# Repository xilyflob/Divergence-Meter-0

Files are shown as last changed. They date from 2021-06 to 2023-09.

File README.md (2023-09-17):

# Purpose
Recreate Tom Titor's original Divergence Meter project with more up to date hardware and software. Also taking into account current tools and services avalible to makers.

# Goals
* Maintain level of visual accuracy to the show that was in the original.
* Keep code size down so if people don't want to use updated hardware they can still fit it on the old chip.
  * Currently failing this, assembly output from the C code has proven much less efficient than I had anticipated.
* Provide more accessible code for the microcontroller so makers can make changes on their own easier than with the assembly version, also commented well enough that it is easy to understand.
* Produce at least proper drawings for the physical construction. Ideally a solid model as well, however there may be license issues with that.

# Software Used
* Autodesk Eagle
  * Originally used to do the PCB design, the SMT versions were later converted to KiCad. Earlier, simpler converts and redesigns currently remain in those file types.
* KiCad
* MPLAB X IDE
  * XC8 compiler
* Solidworks

# Build Log
Available on [Imgur](https://imgur.com/a/QL4b4lS), maybe one day I will make a website for better layout and such.

# Current Status 9/16/23
Long time no update :)

Lost lots of motivation to work on this after I realized that there are more I2C issues. Regular writes flat out dont work, you make it though the code but they don't take on the RTC. Currently implementing a fix that is reccomended in the 8803 manual, hopefully it works.

No changes to hardware this time, I do have a bunch of ideas for a Rev B including actually hooking up the INT line from the RTC which could prove EXTREMELY useful in making the software less "busy".

Motivation remains hard, hope to keep at this as well as I can.

# Background
Full disclosure time, I have zero formal training in coding or electrical engineering, I am actually a machinist (I guess that makes me qualified to fab the actual box though). On top of this, this is my first time doing any assembly reading, C coding, coding for microchips, or circuit board design. If I make a mistake that you see, PLEASE tell me.

I've wanted to do Tom's divergence meter project basically since I first found it after watching the Steins;Gate show. Never actually had the drive to do it though. Don't ask me why, but at some point in 2021 I went to look at the site, only to find it gone. Wayback Machine has an archive, but more importantly whoever the saint is that runs brotoro.com made a complete functional rehost of the site, which is much less clunky than Wayback. Would definitely say that almost losing that info really pushed me to start working on this.

# Thanks
* Jonathan from [SWISSNIXIE](http://www.swissnixie.com/) for helping me understand nixie tube amperage and resistance requirement as well as lending prototyping advice on the HV5623 drivers.
* John from [Taylor Electronics](https://www.shop-tes.com/) for providing data on the current usage of the 1364 HVPS in this specific application.
* /r/PrintedCircuitBoard for doing their best to answer my questions

# Licence
Hardware: Creative Commons Attribution-ShareAlike 4.0 International

Software: GNU GPL V3.0

Also just let me know if you use anything. Or if you make this! Would love to see people's projects.

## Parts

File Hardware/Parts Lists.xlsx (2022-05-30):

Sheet: Tom Titor Parts List
Quantity | Part | Description | Mouser Part # | Source/Price | Notes
1 |  | Main Printed Circuit Board
1 |  | Tube Printed Circuit Board
1 | U3 | PIC16F628A processor | 579-PIC16F628A-E/P or 579-PIC16F628A-I/P | mouser.com $2.23
1 | U1 | LM7805 1A 5V regulator TO-220 | 512-LM7805CT | mouser.com $0.62
1 | D1 | 1N4007 | 512-1N4007 | mouser.com $0.09
1 | F1 | Fuse 0.8A 5mm x 20mm | 504-BK/S500-800-R | mouser.com $0.21
2 | F1 | Fuse Holder Clips | 534-3519 | mouser.com $0.13 each
1 | J2 | DC Power Jack 2.5mm | 806-KLDX-0202-B | mouser.com $0.66
1 | X2 | Crystal 32.768 KHz 12.5 pF 20ppm* | 559-NC38-LF | mouser.com $0.63 | Not needed if using the DS3232 clock
1 | U4 | DS1307+ Real Time Clock* | 700-DS1307 | mouser.com $4.03 | Not needed if using the DS3232 clock
1 | U2 | 1364 High Voltage Power Supply | 1364 HVPS-H | tayloredge.com $13.95
1 | C2 | 330uF Electrolytic Capacitor |  | (comes with 1364 HVPS-H)
3 | U6, U7, U8 | Supertex Serial to Parallel Converter | 689-HV5622PG-G | mouser.com $7.51 each | 220V 32Ch Open Drain Outputs
8 | T0-7 | IN-14 Nixie Tubes |  | eBay | I recommend getting tubes that are "New Old Stock" and "guaranteed tested" (or test them yourself before you install them)
1 | C1 | 33uF Electrolytic Capacitor | 140-RGA330M1EBK0511G | mouser.com $0.08
5 | C3, C4*, C8, C9, C10 | 0.1uF Capacitor MLCC | 810-FK18X7R1H104K | mouser.com $0.21 | C4 not needed if using the DS3232 clock
5 | R1, R2, R3, R4, R32 | 10K Resistor | 660-CF1/4C103J | mouser.com $0.15 each
1 | R31 | 470K Resistor | 660-CF1/4C474J | mouser.com $0.15
8 | R7, R8, R9, R10, R11, R12, R13, R14 | 33K Resistors | 271-33K-RC | mouser.com $0.09 each
16 | R15, R16, R17, R18, R19, R20, R21, R22, R23, R24, R25, R26, R27, R28, R29, R30 | 243K Resistor | 271-243K-RC | mouser.com $0.09 each
1 | R5 | Trimmer Resistor 100K Sealed 6mm Square 12-turn | 81-PV37W104C01B00 | mouser.com $2.35
1 | J1 | 8 Pin header female | 575-010064 | mouser.com $8.85
1 | J3 | 6 Pin header female
3 | NC1-3 | 2 Pin header female
1 | J4 | 8 Pin header male | 575-093050 | mouser.com $8.39
3 | NC4-6 | 2 Pin header male
1 | U3 | 18-pin DIP Socket | 571-1-390261-5 | mouser.com $0.22
1 | B1 | Battery Holder for B1 | 534-103 | mouser.com $1.50
1 | B1 | CR2032 3V Lithium coin cell | 658-CR2032 | mouser.com $0.45
2 | SW1, SW2 | Micro miniature tactile switch | 655-FSMRA4JH | mouser.com $0.25 each
1 | SW3 | Slide Switch SPDT Right-Angle PC mount | 102-1261-EV | mouser.com $2.92 | not on mouser anymore, try 103-5007-EV
1 | B2 | 9V Battery Snap Connector | 270-324 | radioshack ($2.99 for pk. of 5)
1 | D2 | LED T-1 3mm (optional) | 78-TLHY4400 or 604-WP710A10YD | mouser.com $0.13 | only needed for debugging
1 | R6 | 270 Ohm (optional) | 660-CF1/4C271J | mouser.com $0.15
1 |  | Power Adapter 9V | PSSMV1USA | amazon.com $18.25 | Velleman Compact Universal DC Adapter Power Supply. The tip that matches power jack J2 has a 2.5mm inside contact diameter, and a 5.5mm outside diameter, with the +9 volts on the center contact and Ground on the barrel.
1 | U5 | Maxim DS3232SN# | 700-DS3232SN# | mouser.com $9.39 | alternative DS3232S#
1 | C7 | 0805 0.1uF Capacitor | 810-CGJ4J2X7R1H104K | mouser.com $0.09
1 | D3 | 1N5817 Schottky Diode | 512-1N5817 | mouser.com $0.43 | optional safety diode for battery protection
1 | SJ1 | Solder bridge |  |  | optional direct battery connection
1 | X1 |  |  |  | Not used
2 | C5,C6 |  |  |  | Not used
1 |  | Small machine screw |  |  | mounting U1
1 |  | PQFP-44 package |  |  | silk screen for U6-8

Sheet: Component Update Parts List
Quantity | Part | Description | Mouser Part # | Source/Price | Notes | General rule: always check buying in 10+ qty for better prices
1 |  | Main Printed Circuit Board |  |  |  | Updated component
1 |  | Tube Printed Circuit Board
1 | U3 | PIC16F628A processor | 579-PIC16F628A-E/P or 579-PIC16F628A-I/P | mouser.com $2.36
1 | U1 | MC7805 1A 5V regulator TO-220 | 863-MC7805CTG | mouser.com $0.62 | Original obsolete
1 | D1 | 1N4007 | 863-1N4007RLG | mouser.com $0.18 | Original obsolete
1 | F1 | Fuse 0.8A 5mm x 20mm | 504-BK1-S500-800-R | mouser.com $0.81 | Original fuse was $3, ridiculous
2 | F1 | Fuse Holder Clips | 534-3519 | mouser.com $0.21 each
1 | J2 | DC Power Jack 2.5mm | 806-KLDX-0202-B | mouser.com $0.54
1 | X2 | Crystal 32.768 KHz 12.5 pF 20ppm* | 559-NC38-LF | mouser.com $0.45 | Not needed if using the DS3232 clock
1 | U4 | DS1307+ Real Time Clock* | 700-DS1307 | mouser.com $3.97 | Not needed if using the DS3232 clock
1 | U2 | 1364 High Voltage Power Supply | 1364 HVPS-H | shop-tes.com $15.00
1 | C2 | 330uF Electrolytic Capacitor |  | (comes with 1364 HVPS-H)
3 | U6, U7, U8 | Supertex Serial to Parallel Converter | 689-HV5622PG-G | mouser.com $6.86 each
8 | T0-7 | IN-14 Nixie Tubes |  | eBay
1 | C1 | 33uF Electrolytic Capacitor | 647-UPW1E330MDD1TD | mouser.com $0.26 | Original now special order, other options also available
5 | C3, C4*, C8, C9, C10 | 0.1uF Capacitor MLCC | 810-FG18X7R1H104KNT0 | mouser.com $0.21 | Original not recommended for new designs. C4 not needed if using the DS3232 clock
5 | R1, R2, R3, R4, R32 | 10K Resistor | 660-CF1/4C103J | mouser.com $0.15 each
1 | R31 | 470K Resistor | 660-CF1/4C474J | mouser.com $0.15
8 | R7, R8, R9, R10, R11, R12, R13, R14 | 33K Resistors | 660-MF1/4DC3302F | mouser.com $0.055 each | Original only available in 1,000 qty., alternatives available.
16 | R15, R16, R17, R18, R19, R20, R21, R22, R23, R24, R25, R26, R27, R28, R29, R30 | 243K Resistor | 660-MF1/4DC2433F | mouser.com $0.055 each | Original only available in 200 qty.
1 | R5 | Trimmer Resistor 100K Sealed 6mm Square 12-turn | 81-PV37W104C01B00 | mouser.com $2.08
1 | J1 | 8 Pin header female | 575-010064 | mouser.com $8.39
1 | J3 | 6 Pin header female
3 | NC1-3 | 2 Pin header female
1 | J4 | 8 Pin header male | 575-093050 | mouser.com $7.14
3 | NC4-6 | 2 Pin header male
1 | U3 | 18-pin DIP Socket | 571-1-2199298-5 | mouser.com $0.30 | Original obsolete
1 | B1 | Battery Holder for B1 | 534-103 | mouser.com $1.51
1 | B1 | CR2032 3V Lithium coin cell | 658-CR2032 | mouser.com $0.33 | Drug store reccomended
2 | SW1, SW2 | Micro miniature tactile switch | 506-FSMRA4JH04 | mouser.com $0.25 each | Original obsolete
1 | SW3 | Slide Switch SPDT Right-Angle PC mount | 118-5MS1S102AM6QES | mouser.com $2.52 | Original mfr. seems to have rebranded
1 | B2 | 9V Battery Snap Connector | 534-232 | mouser.com $0.48 | Lmao RadioShack
1 | D2 | LED T-1 3mm (optional) | 78-TLHY4400 or 604-WP710A10YD | mouser.com $0.49 | Debug only
1 | R6 | 270 Ohm (optional) | 660-CF1/4C271J | mouser.com $0.15 | Debug only
1 |  | Power Adapter 9V | 418-TRE15090A12G13VI | mouser.com $13.70 | Original not for sale anymore. Requirements 9V output (800mA and 10W minimum per original), 2.5x5.5mm barrel, positive center, gnd outer
1 | U5 | Maxim DS3232SN# | 700-DS3232SN# | mouser.com $9.09 | Alternative clock. DS3232S# can be used as well.
1 | C7 | 0805 0.1uF Capacitor | 810-C2012X7R1H104KAE | mouser.com $0.24 | Original not recommended for new designs. Used if using the DS3232 clock option.
1 | D3 | 1N5817 Schottky Diode | 511-1N5817 | mouser.com $0.40 | Original obsolete. Optional safety diode for battery protection
1 | SJ1 | Solder bridge |  |  | Optional direct battery connection
1 | X1 |  |  |  | Not used
2 | C5,C6 |  |  |  | Not used
1 |  | Small machine screw |  |  | mounting U1
1 |  | PQFP-44 package |  |  | silk screen for U6-8

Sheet: Thru Hole Update Parts List
Quantity | Part | Description | Mouser Part # | Source/Price | Notes | General rule: always check buying in 10+ qty for better prices
1 |  | Main Printed Circuit Board
1 |  | Tube Printed Circuit Board
1 | U3 | PIC16F628A processor | 579-PIC16F628A-E/P or 579-PIC16F628A-I/P | mouser.com $2.36
1 | U1 | MC7805 1A 5V regulator TO-220 | 863-MC7805CTG | mouser.com $0.62
1 | D1 | 1N4007 | 863-1N4007RLG | mouser.com $0.18
1 | F1 | Fuse 0.8A 5mm x 20mm | 504-BK1-S500-800-R | mouser.com $0.81
2 | F1 | Fuse Holder Clips | 534-3519 | mouser.com $0.21 each
1 | J2 | DC Power Jack 2.5mm | 806-KLDX-0202-B | mouser.com $0.54
1 | U2 | 1364 High Voltage Power Supply | 1364 HVPS-H | shop-tes.com $15.00
1 | C2 | 330uF Electrolytic Capacitor |  | (comes with 1364 HVPS-H)
3 | U6, U7, U8 | Supertex Serial to Parallel Converter | 689-HV5622PG-G | mouser.com $6.86 each
8 | T0-7 | IN-14 Nixie Tubes |  | eBay
1 | C1 | 33uF Electrolytic Capacitor | 647-UPW1E330MDD1TD | mouser.com $0.26
5 | C3, C8, C9, C10 | 0.1uF Capacitor MLCC | 810-FG18X7R1H104KNT0 | mouser.com $0.21
5 | R1, R2, R3, R4, R32 | 10K Resistor | 660-CF1/4C103J | mouser.com $0.15 each
1 | R31 | 470K Resistor | 660-CF1/4C474J | mouser.com $0.15
8 | R7, R8, R9, R10, R11, R12, R13, R14 | 33K Resistors | 660-MF1/4DC3302F | mouser.com $0.055 each
16 | R15, R16, R17, R18, R19, R20, R21, R22, R23, R24, R25, R26, R27, R28, R29, R30 | 243K Resistor | 660-MF1/4DC2433F | mouser.com $0.055 each
1 | R5 | Trimmer Resistor 100K Sealed 6mm Square 12-turn | 81-PV37W104C01B00 | mouser.com $2.08
1 | J1 | 8 Pin header female | 575-010064 | mouser.com $8.39
1 | J3 | 6 Pin header female
3 | NC1-3 | 2 Pin header female
1 | J4 | 8 Pin header male | 575-093050 | mouser.com $7.14
3 | NC4-6 | 2 Pin header male
1 | U3 | 18-pin DIP Socket | 571-1-2199298-5 | mouser.com $0.30
1 | B1 | Battery Holder for B1 | 534-103 | mouser.com $1.51
1 | B1 | CR2032 3V Lithium coin cell | 658-CR2032 | mouser.com $0.33
2 | SW1, SW2 | Micro miniature tactile switch | 506-FSMRA4JH04 | mouser.com $0.25 each
1 | SW3 | Slide Switch SPDT Right-Angle PC mount | 118-5MS1S102AM6QES | mouser.com $2.52
1 | B2 | 9V Battery Holder | 534-1291 | mouser.com $3.78
1 | D2 | LED T-1 3mm (optional) | 78-TLHY4400 or 604-WP710A10YD | mouser.com $0.49 | Only needed for debugging
1 | R6 | 270 Ohm (optional) | 660-CF1/4C271J | mouser.com $0.15 | Only needed for debugging
1 |  | Power Adapter 9V | 418-TRE15090A12G13VI | mouser.com $13.70 | Requirements 9V output (800mA and 10W minimum per origional), 2.5x5.5mm barrel, positive center, gnd outer
1 | U5 | Maxim DS3232SN# | 700-DS3232SN# | mouser.com $9.09
1 | C7 | 0805 0.1uF Capacitor | 810-C2012X7R1H104KAE | mouser.com $0.24
1 | D3 | 1N5817 Schottky Diode | 511-1N5817 | mouser.com $0.40 | Optional safety diode for battery protection
1 | SJ1 | Solder bridge |  |  | Optional direct battery connection
1 |  | Small machine screw |  |  | mounting U1
1 |  | PQFP-44 package |  |  | silk screen for U6-8

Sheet: SMT Redesign
Part | Description | Source | Link | Quantity | Price (ea.) | Notes | General rule: always check buying in 10+ qty for better prices
B1 | CR2032 3V Lithium coin cell | Local Store |  | 1 |  | Circuit was designed using a Energizer datasheet
B1C | Horiz 20mm Battery Holder | Mouser | 534-103 | 1 | $1.82
B2 | 9-12V battery of some sort
B2C | 3 Wire Vert Connector | Mouser | 538-53253-0370 | 1 | $0.27 | Battery connector
B3C | 3 Wire Male Connector (optional) | Mouser | 538-51065-0300 | 1 | $0.26 | Mates with B2C
B3CC | Crimp Wire Connection (optional) | Mouser | 538-50212-8100 | 3 | $0.30 | Wire end crimps for B3C
C1 | 1µF MLCC | Mouser | 187-CL21B105KAFNFNE | 1 | $0.12
C2 | 2.2µF MLCC | Mouser | 187-CL21B225KAFNFNE | 1 | $0.21
C3 | 330µF Electrolytic Capacitor | Mouser | 647-UCM1C331MCL1GS | 1 | $0.74 | John at Taylor Electronics has oked this as a replacement for 667-EEU-FC1C331 per HVPS datasheet
C4, C5, C8, C9, C10 | 0.1µF MLCC | Mouser | 187-CL21B104KBCNNNC | 5 | $0.11
D1 | MRA4007 1A 1000V Recovery Rectifier | Mouser | 863-MRA4007T3G | 1 | $0.39
D2 | DCC Schottky Diode | Mouser | 726-BAS7005WH6327 | 1 | $0.51 | Near idendical offerings from Nexperia and Diodes Incorporated
D3 | LED T-1 3mm (optional) | Mouser | 78-TLHY4400 or 604-WP710A10YD | 1 | $0.28 | Only needed for debugging
F1 | Fuse 0.8A 5mm x 20mm | Mouser | 504-BK/S500-800-R | 1 | $0.40 | Fast Blow
F1C | Fuse Holder Clips | Mouser | https://octopart.com/3519-keystone-45750?r=sp | 2 | $0.25
J1 | 7 Pin .1" Pitch Header Female | Mouser | https://octopart.com/801-41-050-10-001000-mill-max-25804236?r=sp | 1 | $8.39 | Cut to length
J2 | 7 Pin .1" Pitch Header Male | Mouser | https://octopart.com/800-10-064-10-001000-mill-max-258892?r=sp | 1 | $7.24 | Cut to length
J3 | 5 Pin .1" Pitch Header Male | Mouser | See J2 | 1
J4 | DC Power Jack 2.5mm | Mouser | 806-KLDX-0202-B | 1 | $0.68 | unsure on quality
NC1-4 | 1 or 2 Pin .1" Pitch Header Female | Mouser | See J1 | 3
NC5-8 | 1 or 2 Pin .1" Pitch Header Male | Mouser | See J2 | 3
R1, R2, R3 | 10K Resistor | Mouser | 603-AC0805FR-7W10KL | 5 | $0.11 | 660-RK73H2ATTD1002F alternative, aestetic choice
R4, R5 | 4.7K Resistor | Mouser | 660-RK73H2ATTD4701F | 2 | $0.10
R6 | 470K Resistor | Mouser | 603-RC0805FR-10470KL | 1 | $0.13
R7 | Trimmer Resistor 100K Sealed 6mm Square 12-turn | Mouser | 652-3224W-1-104E | 1 | $5.01
R8 | 270 Ohm (optional) | Mouser | 660-CF1/4C271J | 1 | $0.15 | Only needed for debugging
R9, R10, R11, R12, R13, R14, R15, R16, R17, R18, R19, R20, R21, R22, R23, R24 | 243K Resistor | Mouser | 71-CRCW2010243KFKEF | 16 | $0.26 | This or equivelents can be extremely difficult to find
R25, R26, R27, R28, R29, R30, R31, R32 | 33K Resistors | Mouser | 279-CRGP2512F33K | 8 | $0.56
SW1, SW2 | Micro miniature tactile switch | Mouser | 506-FSMRA4JH04 | 2 | Mouser
SW3 | Slide Switch SPDT Right-Angle PC mount | Mouser | 612-500SSP3S1M6QEA | 1 | $3.54
T0-7 | IN-14 Nixie Tubes | eBay | IN-14 | 8
T0-7 | Pin sockets for 0.5mm wire | eBay or others |  | 104 |  | Any pin socket will do, must fit 0.5mm wire, better quality options than ebay are around
U1 | TLV767-Q1 Fixed 5V Linear Voltage Regulator | Mouser | 595-TLV76750QWDRBRQ1 | 1 | $1.51
U2 | 1364 High Voltage Power Supply | Taylor Electronics | 1364 HVPS-H | 1 | $15.00
U3 | Microchip PIC16F18444 | Mouser | 579-PIC16F18444E/GZ | 1 | $1.27 | Direct from Microchip is also an option
U4 | Micro Crystal RV-8803-C7 | Mouser | 428-202677-MG01 | 1 | $2.96 | Depends on your choice of board. DS3232S# is the other option.
U5, U6, U7 | Microchip HV5623 | Mouser | 689-HV5623K7-G | 3 | $7.99
 | Main Printed Circuit Board |  |  | 1
 | Tube Printed Circuit Board |  |  | 1
 | Power Adapter 9-12V | Mouser | 418-TRE15090A12G13VI or 418-TRG1512A12E03VI | 1 | $12.50 | 9V Requirements: 800mA and 10W, 2.5x5.5mm barrel, positive center, gnd outer; 12V Requirements: ???mA and ???W, 2.5x5.5mm barrel, positive center, gnd outer
 |  |  |  |  | Prices as of 6/12/21

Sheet: Physical Construction
Quantity | Part | Source | Part # @ Source | Description | Notes
9 |  | mouser.com $0.20 each | 647-UPW1A220MDD | Black Electrolytic Capacitors, 5mm diameter by 11mm long
1 |  | mouser.com $2.45 | 598-EDLF473A5R5C | Supercapacitor (lower-left part of board)
1 |  | radioshack ($1.89 for 2) | 272-0126 | Ceramic Disc Capacitor, ~4mm dia.
2 |  | mouser.com $0.18 | 771-74HC138N or 771-HEF4094BP652 | IC 14-pin DIP (any chip this size is fine...I used what I had lying around...the part numbers here are the cheapest chips I found at Mouser.com). These go behind the tubes.
1 |  | mouser.com $0.52 | 511-L7809CP or 511-L7805CP | TO-220 package device (I can't tell for sure what component is back there, so I stuck this in. I like the look of the all-plastic TO-220FP package here, but a metal-tabbed device is fine, too.)
1 |  | mouser.com $0.09 | 512-1N4007 | Small Diode. DO-41 package.
7 |  | mouser.com $0.15 each | 660-CF1/4C113J | Beige Resistors, 1/4 watt. I used 11K.
5 |  | mouser.com $0.14 each | 660-MF1/4CC2742F | Blue Resistors, 1/4 watt, metal film 1% (those are blue ones). I used 27.4K
4 |  |  |  | Yellow Capacitors... Well, I couldn't find nice yellow capacitors of the correct shape. You may have to spray paint some. Mouser 667-ECQ-V1H273JL2 might be a bit large. Mouser 810-FK20X7R1H684K might be a bit small. Mouser 647-QYX1H102JTP3TA are actually yellow, but taller than we want. | 80-C356C104J5G5TA
4 | Mounting Pillars | mouser.com $1.02 each | 534-9070

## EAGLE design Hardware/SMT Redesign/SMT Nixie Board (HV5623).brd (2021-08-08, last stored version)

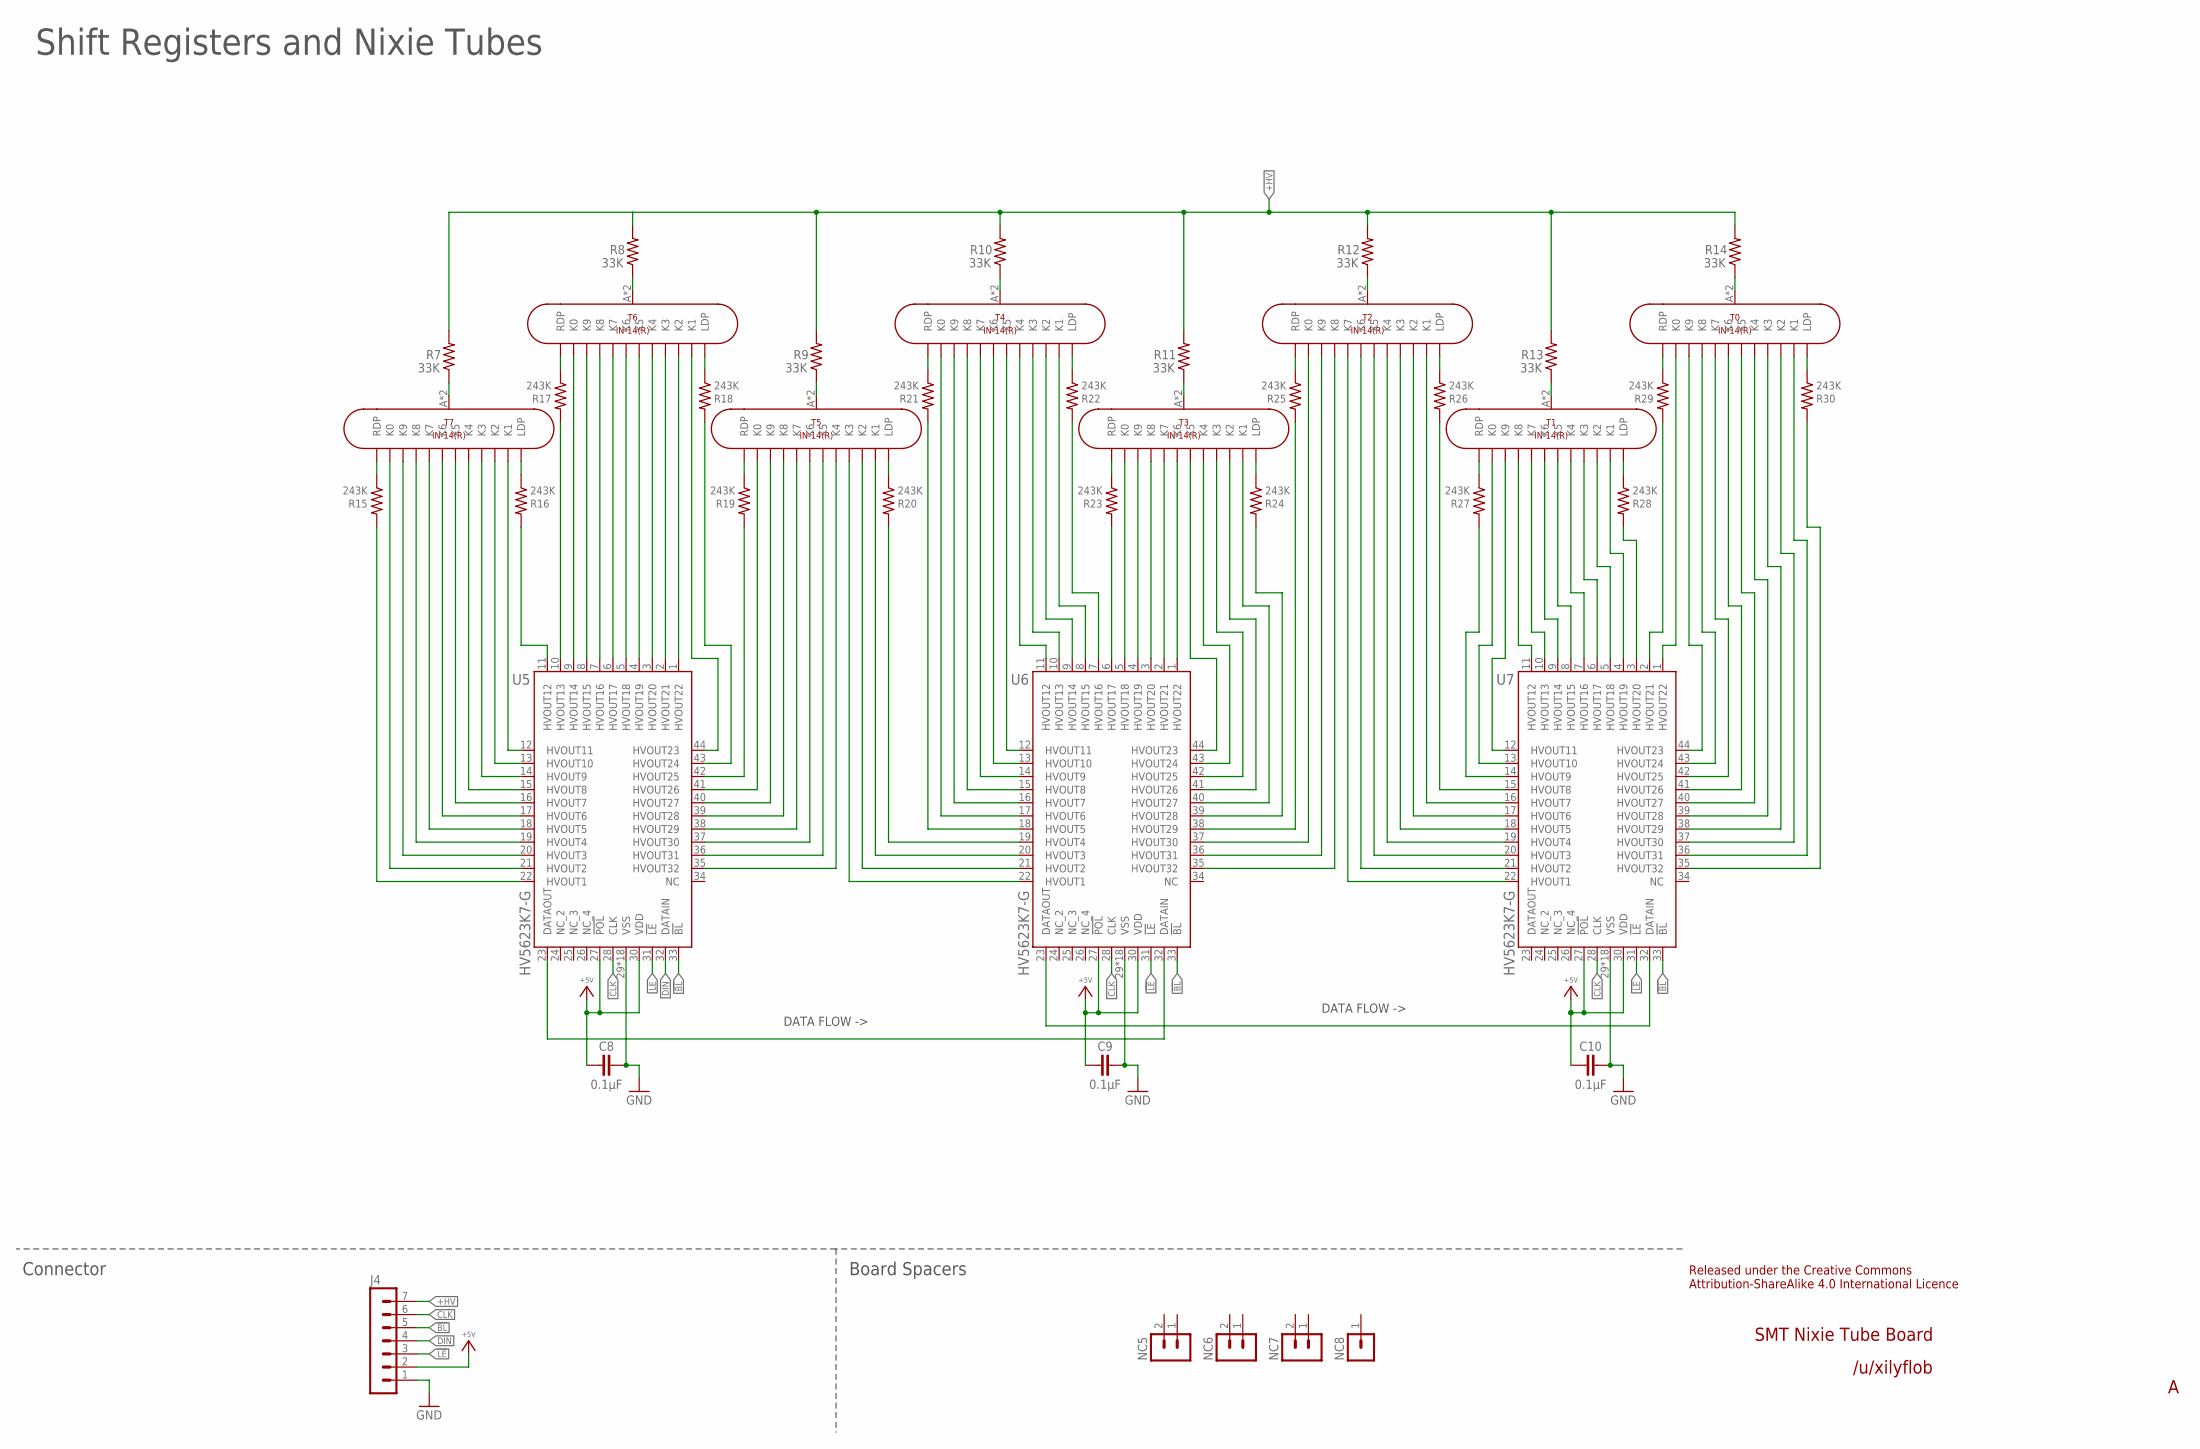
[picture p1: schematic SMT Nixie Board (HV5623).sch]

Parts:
C8, C9, C10: 0.1µF; C0805
J4: 1; MA07
NC5, NC6, NC7: MA02
NC8: MA01
R7, R8, R9, R10, R11, R12, R13, R14: 33K; R2512
R15, R16, R17, R18, R19, R20, R21, R22, R23, R24, R25, R26, R27, R28, R29, R30: 243K; R2010
T0, T1, T2, T3, T4, T5, T6, T7: IN-14(R); IN-14_REVERSE
U5, U6, U7: HV5623K7-G; WQFN-44

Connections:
!BL!: J4.5, U5.33 (!BL), U6.33 (!BL), U7.33 (!BL)
!LE!: J4.3, U5.31 (!LE), U6.31 (!LE), U7.31 (!LE)
+5V: C8.1, C9.1, C10.1, J4.2, U5.27 (!POL), U5.30 (VDD), U6.27 (!POL), U6.30 (VDD), U7.27 (!POL), U7.30 (VDD)
+HV: J4.7, R7.2, R8.2, R9.2, R10.2, R11.2, R12.2, R13.2, R14.2
CLK: J4.6, U5.28 (CLK), U6.28 (CLK), U7.28 (CLK)
DIN: J4.4, U5.32 (DATAIN)
GND: C8.2, C9.2, C10.2, J4.1, U5.29 (VSS), U5.P$1 (VSS), U5.P$2 (VSS), U5.P$3 (VSS), U5.P$4 (VSS), U5.P$5 (VSS), U5.P$6 (VSS), U5.P$7 (VSS), U5.P$8 (VSS), U5.P$9 (VSS), U5.P$10 (VSS), U5.P$11 (VSS), U5.P$12 (VSS), U5.P$13 (VSS), U5.P$14 (VSS), U5.P$15 (VSS), U5.P$16 (VSS), U5.TP (VSS), U6.29 (VSS), U6.P$1 (VSS), U6.P$2 (VSS), U6.P$3 (VSS), U6.P$4 (VSS), U6.P$5 (VSS), U6.P$6 (VSS), U6.P$7 (VSS), U6.P$8 (VSS), U6.P$9 (VSS), U6.P$10 (VSS), U6.P$11 (VSS), U6.P$12 (VSS), U6.P$13 (VSS), U6.P$14 (VSS), U6.P$15 (VSS), U6.P$16 (VSS), U6.TP (VSS), U7.29 (VSS), U7.P$1 (VSS), U7.P$2 (VSS), U7.P$3 (VSS), U7.P$4 (VSS), U7.P$5 (VSS), U7.P$6 (VSS), U7.P$7 (VSS), U7.P$8 (VSS), U7.P$9 (VSS), U7.P$10 (VSS), U7.P$11 (VSS), U7.P$12 (VSS), U7.P$13 (VSS), U7.P$14 (VSS), U7.P$15 (VSS), U7.P$16 (VSS), U7.TP (VSS)
T0A: R7.1, T7.A, T7.A_1 (A)
T1A: R8.1, T6.A, T6.A_1 (A)
T2A: R9.1, T5.A, T5.A_1 (A)
T3A: R10.1, T4.A, T4.A_1 (A)
T4A: R11.1, T3.A, T3.A_1 (A)
T5A: R12.1, T2.A, T2.A_1 (A)
T6A: R13.1, T1.A, T1.A_1 (A)
T7A: R14.1, T0.A, T0.A_1 (A)
U5-T0K0: T7.K0, T7.K0_1 (K0), U5.21 (HVOUT2)
U5-T0K1: T7.K1, T7.K1_1 (K1), U5.12 (HVOUT11)
U5-T0K2: T7.K2, T7.K2_1 (K2), U5.13 (HVOUT10)
U5-T0K3: T7.K3, T7.K3_1 (K3), U5.14 (HVOUT9)
U5-T0K4: T7.K4, T7.K4_1 (K4), U5.15 (HVOUT8)
U5-T0K5: T7.K5, T7.K5_1 (K5), U5.16 (HVOUT7)
U5-T0K6: T7.K6, T7.K6_1 (K6), U5.17 (HVOUT6)
U5-T0K7: T7.K7, T7.K7_1 (K7), U5.18 (HVOUT5)
U5-T0K8: T7.K8, T7.K8_1 (K8), U5.19 (HVOUT4)
U5-T0K9: T7.K9, T7.K9_1 (K9), U5.20 (HVOUT3)
U5-T0LDP: R16.2, U5.11 (HVOUT12)
U5-T0LDP1: R16.1, T7.LDP, T7.LDP_1 (LDP)
U5-T0RDP: R15.2, U5.22 (HVOUT1)
U5-T0RDP1: R15.1, T7.RDP, T7.RDP_1 (RDP)
U5-T1K0: T6.K0, T6.K0_1 (K0), U5.9 (HVOUT14)
U5-T1K1: T6.K1, T6.K1_1 (K1), U5.44 (HVOUT23)
U5-T1K2: T6.K2, T6.K2_1 (K2), U5.1 (HVOUT22)
U5-T1K3: T6.K3, T6.K3_1 (K3), U5.2 (HVOUT21)
U5-T1K4: T6.K4, T6.K4_1 (K4), U5.3 (HVOUT20)
U5-T1K5: T6.K5, T6.K5_1 (K5), U5.4 (HVOUT19)
U5-T1K6: T6.K6, T6.K6_1 (K6), U5.5 (HVOUT18)
U5-T1K7: T6.K7, T6.K7_1 (K7), U5.6 (HVOUT17)
U5-T1K8: T6.K8, T6.K8_1 (K8), U5.7 (HVOUT16)
U5-T1K9: T6.K9, T6.K9_1 (K9), U5.8 (HVOUT15)
U5-T1LDP: R18.2, U5.43 (HVOUT24)
U5-T1LDP1: R18.1, T6.LDP, T6.LDP_1 (LDP)
U5-T1RDP: R17.2, U5.10 (HVOUT13)
U5-T1RDP1: R17.1, T6.RDP, T6.RDP_1 (RDP)
U5-T2K0: T5.K0, T5.K0_1 (K0), U5.41 (HVOUT26)
U5-T2K4: T5.K4, T5.K4_1 (K4), U5.35 (HVOUT32)
U5-T2K5: T5.K5, T5.K5_1 (K5), U5.36 (HVOUT31)
U5-T2K6: T5.K6, T5.K6_1 (K6), U5.37 (HVOUT30)
U5-T2K7: T5.K7, T5.K7_1 (K7), U5.38 (HVOUT29)
U5-T2K8: T5.K8, T5.K8_1 (K8), U5.39 (HVOUT28)
U5-T2K9: T5.K9, T5.K9_1 (K9), U5.40 (HVOUT27)
U5-T2RDP: R19.2, U5.42 (HVOUT25)
U5-T2RDP1: R19.1, T5.RDP, T5.RDP_1 (RDP)
U5-U6: U5.23 (DATAOUT), U6.32 (DATAIN)
U6-T2K1: T5.K1, T5.K1_1 (K1), U6.20 (HVOUT3)
U6-T2K2: T5.K2, T5.K2_1 (K2), U6.21 (HVOUT2)
U6-T2K3: T5.K3, T5.K3_1 (K3), U6.22 (HVOUT1)
U6-T2LDP: R20.2, U6.19 (HVOUT4)
U6-T2LDP1: R20.1, T5.LDP, T5.LDP_1 (LDP)
U6-T3K0: T4.K0, T4.K0_1 (K0), U6.17 (HVOUT6)
U6-T3K1: T4.K1, T4.K1_1 (K1), U6.8 (HVOUT15)
U6-T3K2: T4.K2, T4.K2_1 (K2), U6.9 (HVOUT14)
U6-T3K3: T4.K3, T4.K3_1 (K3), U6.10 (HVOUT13)
U6-T3K4: T4.K4, T4.K4_1 (K4), U6.11 (HVOUT12)
U6-T3K5: T4.K5, T4.K5_1 (K5), U6.12 (HVOUT11)
U6-T3K6: T4.K6, T4.K6_1 (K6), U6.13 (HVOUT10)
U6-T3K7: T4.K7, T4.K7_1 (K7), U6.14 (HVOUT9)
U6-T3K8: T4.K8, T4.K8_1 (K8), U6.15 (HVOUT8)
U6-T3K9: T4.K9, T4.K9_1 (K9), U6.16 (HVOUT7)
U6-T3LDP: R22.2, U6.7 (HVOUT16)
U6-T3LDP1: R22.1, T4.LDP, T4.LDP_1 (LDP)
U6-T3RDP: R21.2, U6.18 (HVOUT5)
U6-T3RDP1: R21.1, T4.RDP, T4.RDP_1 (RDP)
U6-T4K0: T3.K0, T3.K0_1 (K0), U6.5 (HVOUT18)
U6-T4K1: T3.K1, T3.K1_1 (K1), U6.40 (HVOUT27)
U6-T4K2: T3.K2, T3.K2_1 (K2), U6.41 (HVOUT26)
U6-T4K3: T3.K3, T3.K3_1 (K3), U6.42 (HVOUT25)
U6-T4K4: T3.K4, T3.K4_1 (K4), U6.43 (HVOUT24)
U6-T4K5: T3.K5, T3.K5_1 (K5), U6.44 (HVOUT23)
U6-T4K6: T3.K6, T3.K6_1 (K6), U6.1 (HVOUT22)
U6-T4K7: T3.K7, T3.K7_1 (K7), U6.2 (HVOUT21)
U6-T4K8: T3.K8, T3.K8_1 (K8), U6.3 (HVOUT20)
U6-T4K9: T3.K9, T3.K9_1 (K9), U6.4 (HVOUT19)
U6-T4LDP: R24.2, U6.39 (HVOUT28)
U6-T4LDP1: R24.1, T3.LDP, T3.LDP_1 (LDP)
U6-T4RDP: R23.2, U6.6 (HVOUT17)
U6-T4RDP1: R23.1, T3.RDP, T3.RDP_1 (RDP)
U6-T5K0: T2.K0, T2.K0_1 (K0), U6.37 (HVOUT30)
U6-T5K8: T2.K8, T2.K8_1 (K8), U6.35 (HVOUT32)
U6-T5K9: T2.K9, T2.K9_1 (K9), U6.36 (HVOUT31)
U6-T5RDP: R25.2, U6.38 (HVOUT29)
U6-T5RDP1: R25.1, T2.RDP, T2.RDP_1 (RDP)
U6-U7: U6.23 (DATAOUT), U7.32 (DATAIN)
U7-T5K1: T2.K1, T2.K1_1 (K1), U7.16 (HVOUT7)
U7-T5K2: T2.K2, T2.K2_1 (K2), U7.17 (HVOUT6)
U7-T5K3: T2.K3, T2.K3_1 (K3), U7.18 (HVOUT5)
U7-T5K4: T2.K4, T2.K4_1 (K4), U7.19 (HVOUT4)
U7-T5K5: T2.K5, T2.K5_1 (K5), U7.20 (HVOUT3)
U7-T5K6: T2.K6, T2.K6_1 (K6), U7.21 (HVOUT2)
U7-T5K7: T2.K7, T2.K7_1 (K7), U7.22 (HVOUT1)
U7-T5LDP: R26.2, U7.15 (HVOUT8)
U7-T5LDP1: R26.1, T2.LDP, T2.LDP_1 (LDP)
U7-T6K0: T1.K0, T1.K0_1 (K0), U7.13 (HVOUT10)
U7-T6K1: T1.K1, T1.K1_1 (K1), U7.4 (HVOUT19)
U7-T6K2: T1.K2, T1.K2_1 (K2), U7.5 (HVOUT18)
U7-T6K3: T1.K3, T1.K3_1 (K3), U7.6 (HVOUT17)
U7-T6K4: T1.K4, T1.K4_1 (K4), U7.7 (HVOUT16)
U7-T6K5: T1.K5, T1.K5_1 (K5), U7.8 (HVOUT15)
U7-T6K6: T1.K6, T1.K6_1 (K6), U7.9 (HVOUT14)
U7-T6K7: T1.K7, T1.K7_1 (K7), U7.10 (HVOUT13)
U7-T6K8: T1.K8, T1.K8_1 (K8), U7.11 (HVOUT12)
U7-T6K9: T1.K9, T1.K9_1 (K9), U7.12 (HVOUT11)
U7-T6LDP: R28.2, U7.3 (HVOUT20)
U7-T6LDP1: R28.1, T1.LDP, T1.LDP_1 (LDP)
U7-T6RDP: R27.2, U7.14 (HVOUT9)
U7-T6RDP1: R27.1, T1.RDP, T1.RDP_1 (RDP)
U7-T7K0: T0.K0, T0.K0_1 (K0), U7.1 (HVOUT22)
U7-T7K1: T0.K1, T0.K1_1 (K1), U7.36 (HVOUT31)
U7-T7K2: T0.K2, T0.K2_1 (K2), U7.37 (HVOUT30)
U7-T7K3: T0.K3, T0.K3_1 (K3), U7.38 (HVOUT29)
U7-T7K4: T0.K4, T0.K4_1 (K4), U7.39 (HVOUT28)
U7-T7K5: T0.K5, T0.K5_1 (K5), U7.40 (HVOUT27)
U7-T7K6: T0.K6, T0.K6_1 (K6), U7.41 (HVOUT26)
U7-T7K7: T0.K7, T0.K7_1 (K7), U7.42 (HVOUT25)
U7-T7K8: T0.K8, T0.K8_1 (K8), U7.43 (HVOUT24)
U7-T7K9: T0.K9, T0.K9_1 (K9), U7.44 (HVOUT23)
U7-T7LDP: R30.2, U7.35 (HVOUT32)
U7-T7LDP1: R30.1, T0.LDP, T0.LDP_1 (LDP)
U7-T7RDP: R29.2, U7.2 (HVOUT21)
U7-T7RDP1: R29.1, T0.RDP, T0.RDP_1 (RDP)

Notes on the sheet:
/u/xilyflob
Released under the Creative Commons Attribution-ShareAlike 4.0 International Licence
SMT Nixie Tube Board
Shift Registers and Nixie Tubes
Connector
Board Spacers
DATA FLOW ->

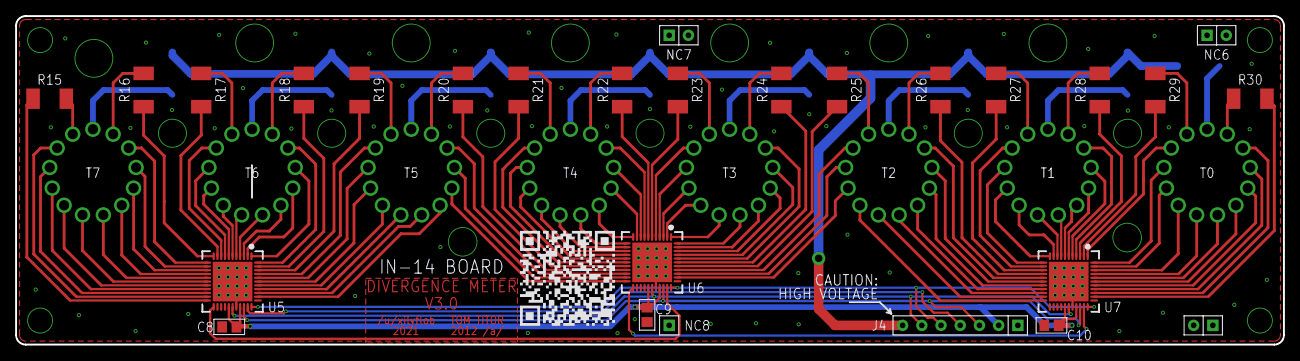
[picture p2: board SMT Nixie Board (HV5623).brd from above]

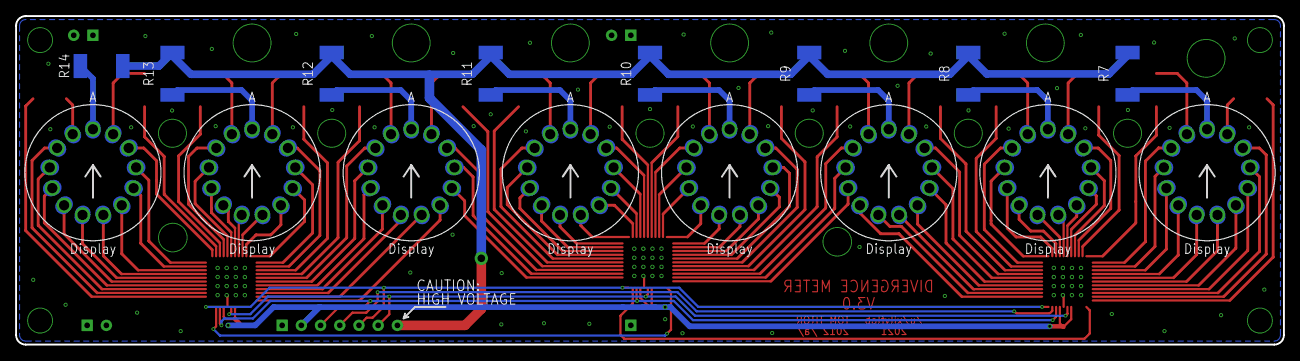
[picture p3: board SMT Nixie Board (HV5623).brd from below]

Board: 2 copper layers, 167.6 x 43.4 mm, 43 parts (16 on the bottom side), 129 nets.

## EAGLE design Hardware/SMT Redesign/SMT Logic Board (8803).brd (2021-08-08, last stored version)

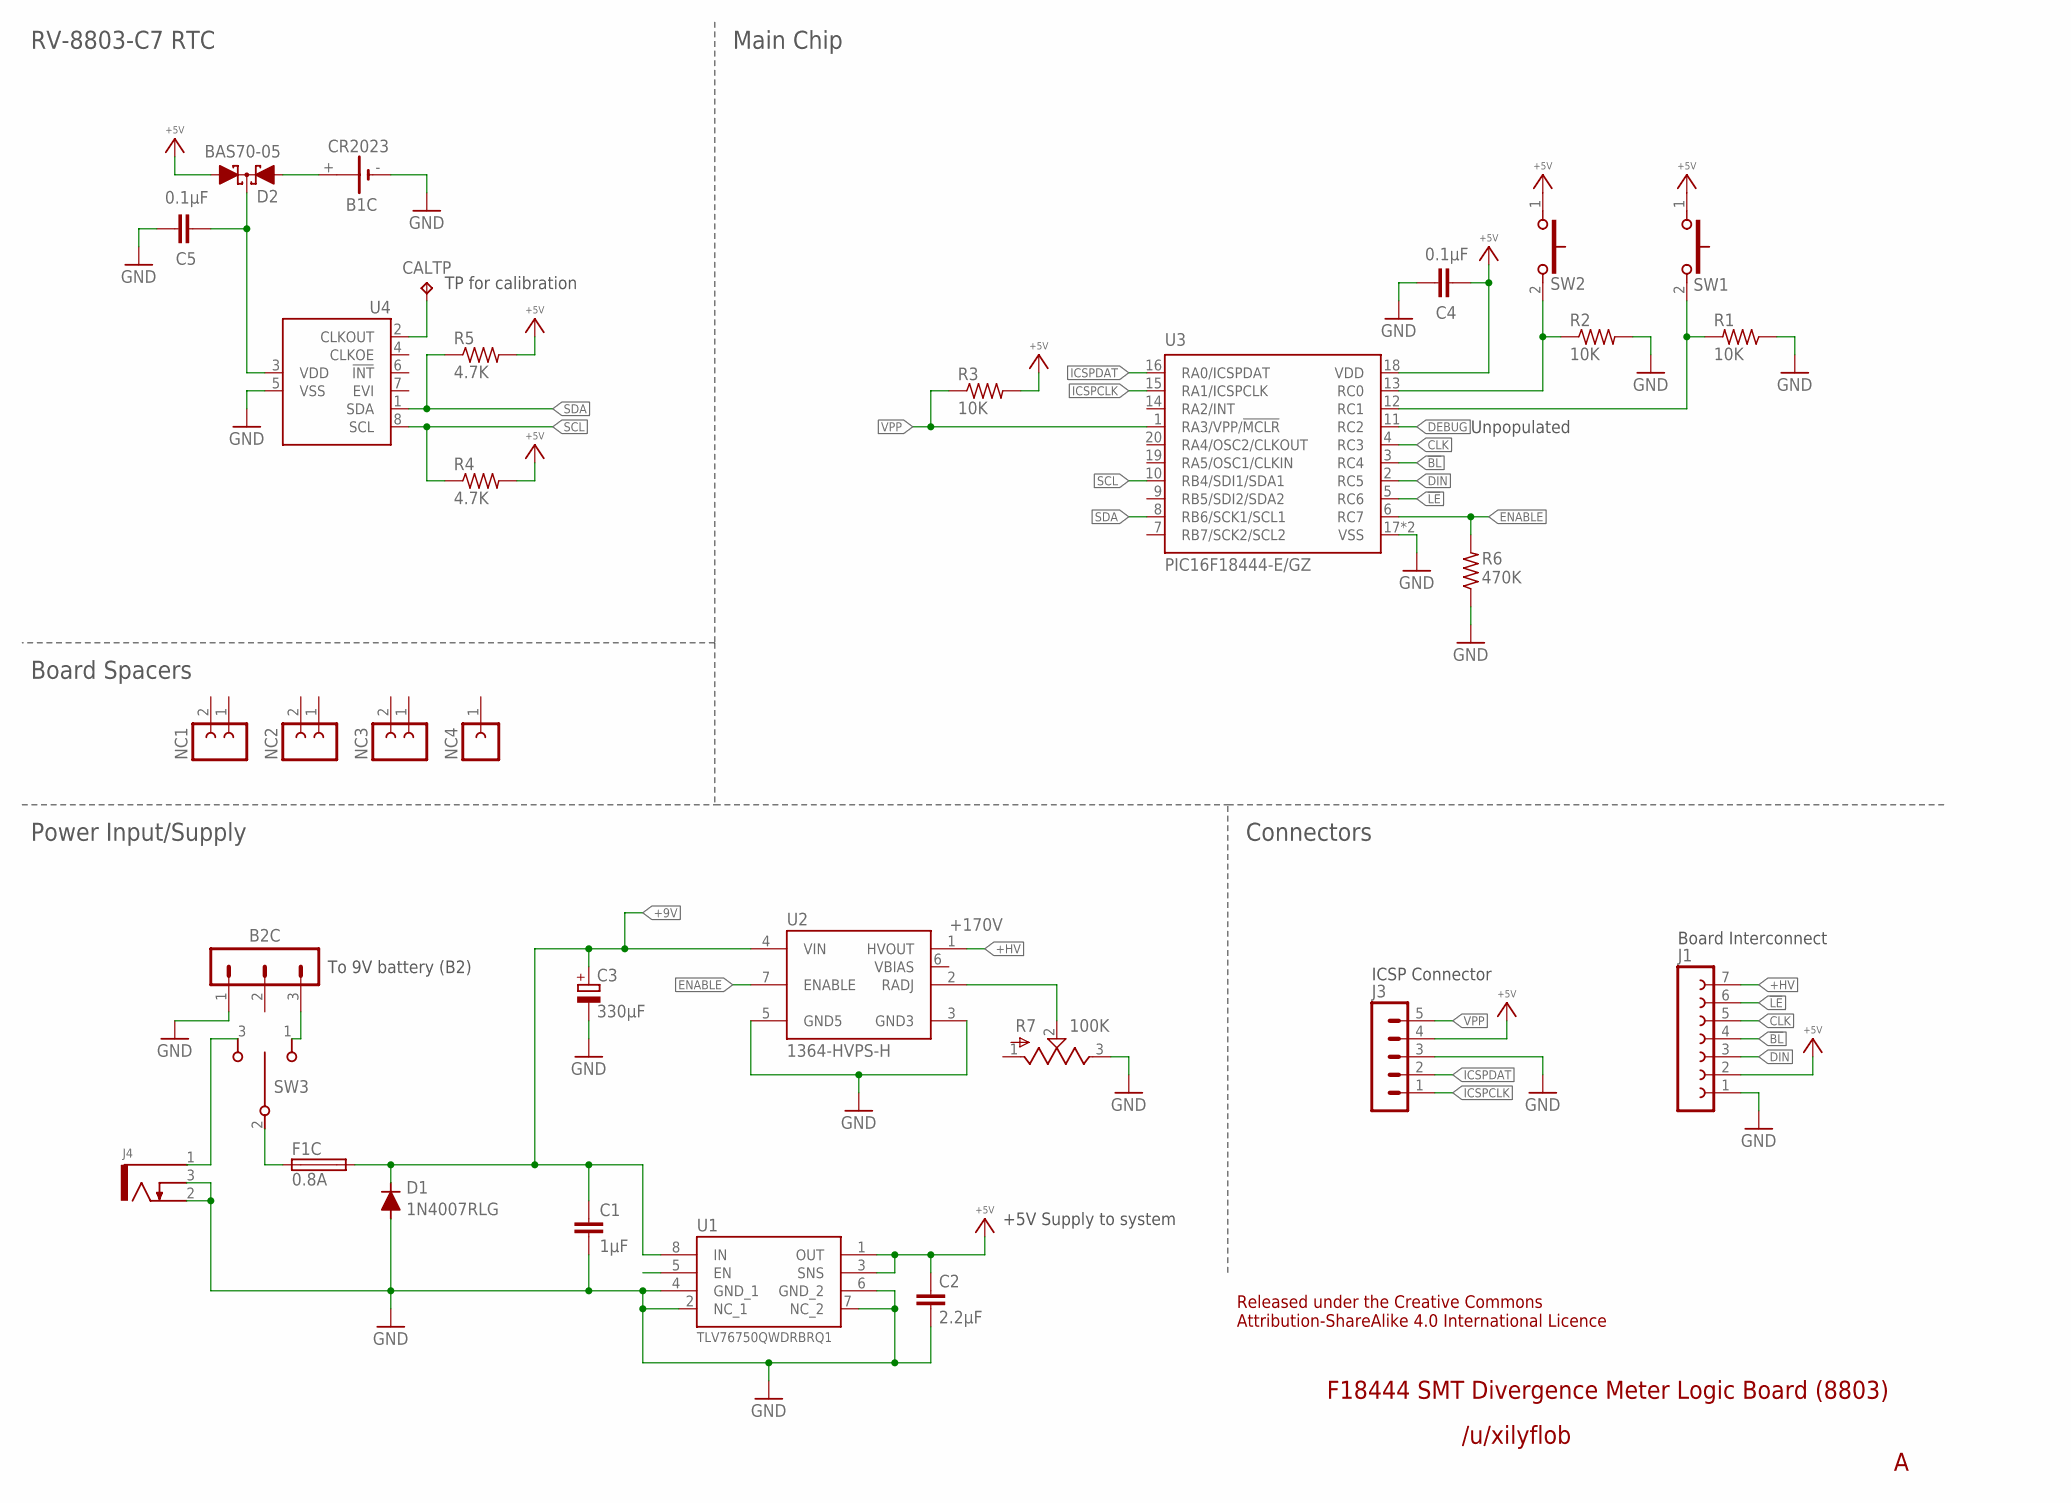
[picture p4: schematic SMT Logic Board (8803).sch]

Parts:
B1C: CR2023; 103
B2C: 53253_3P; 532530370
C1: 1µF; C0805
C2: 2.2μF; C0805
C3: 330µF; 6.3MM_SMD_CHIP
C4, C5: 0.1µF; C0805
CALTP: TPTP18R; TP18R
D1: 1N4007RLG; SMA-403D
D2: BAS70-05; SOT323
F1C: 0.8A; 5X20MM
J1: FE07FE07; FE07
J3: MA05
J4: KLDX-0202-B; KDLX-0202-X
NC1, NC2, NC3: FE02
NC4: FE01
R1, R2, R3: 10K; R0805
R4, R5: 4.7K; R0805
R6: 470K; R0805
R7: 100K; 3224W
SW1, SW2: FSMRA4JH04; FSMRA4JH
SW3: 5MS1S102AM6QES; SLIDE_SPDT_MINI
U1: TLV76750QWDRBRQ1; SON_8_FIXED
U2: 1364-HVPS-H
U3: PIC16F18444-E/GZ; UQFN-20
U4: RV-8803-C7; C7

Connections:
!BL!: J1.4, U3.3 (RC4)
!LE!: J1.6, U3.5 (RC6)
+5V: C2.1, C4.1, D2.2 (A2), J1.2, J3.4, R3.2, R4.2, R5.2, SW1.1, SW2.1, U1.1 (OUT), U1.3 (SNS), U3.18 (VDD)
+9V: C1.1, C3.+, D1.C, F1C.2A (2), F1C.2B (2), U1.8 (IN), U2.4 (VIN)
+9V_1: F1C.1A (1), F1C.1B (1), SW3.2 (COM)
+9V_2: J4.1, SW3.3 (POS_2)
+9V_3: B2C.3, SW3.1 (POS_1)
+HV: J1.7, U2.1 (HVOUT)
CLK: J1.5, U3.4 (RC3)
CLKTEST: CALTP.TP, U4.2 (CLKOUT)
DEBUG: U3.11 (RC2)
DIN: J1.3, U3.2 (RC5)
EN: U1.5 (EN)
ENABLE: R6.2, U2.7 (ENABLE), U3.6 (RC7)
GND: B1C.-, B2C.1, C1.2, C2.2, C3.-, C4.2, C5.2, D1.A, J1.1, J3.3, J4.2, J4.3, R1.1, R2.2, R6.1, R7.3, U1.2 (NC_1), U1.4 (GND_1), U1.6 (GND_2), U1.7 (NC_2), U1.TP, U1.TV_1 (TP), U1.TV_2 (TP), U1.TV_3 (TP), U1.TV_4 (TP), U1.TV_5 (TP), U1.TV_6 (TP), U1.TV_7 (TP), U1.TV_8 (TP), U1.TV_9 (TP), U2.3 (GND3), U2.5 (GND5), U3.17 (VSS), U3.21 (VSS), U4.5 (VSS)
ICSPCLK: J3.1, U3.15 (RA1/ICSPCLK)
ICSPDAT: J3.2, U3.16 (RA0/ICSPDAT)
RADJ: R7.2, U2.2 (RADJ)
RTCPWR: C5.1, D2.3 (C), U4.3 (VDD)
SCL: R4.1, U3.10 (RB4/SDI1/SDA1), U4.8 (SCL)
SDA: R5.1, U3.8 (RB6/SCK1/SCL1), U4.1 (SDA)
SW1: R1.2, SW1.2, U3.12 (RC1)
SW2: R2.1, SW2.2, U3.13 (RC0)
VBAK: B1C.+, D2.1 (A1)
VPP: J3.5, R3.1, U3.1 (RA3/VPP/!MCLR!)

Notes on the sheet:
+170V
To 9V battery (B2)
RV-8803-C7 RTC
Connectors
Board Spacers
Power Input/Supply
Main Chip
/u/xilyflob
Released under the Creative Commons Attribution-ShareAlike 4.0 International Licence
F18444 SMT Divergence Meter Logic Board (8803)
+5V Supply to system
Unpopulated
Board Interconnect
ICSP Connector
TP for calibration

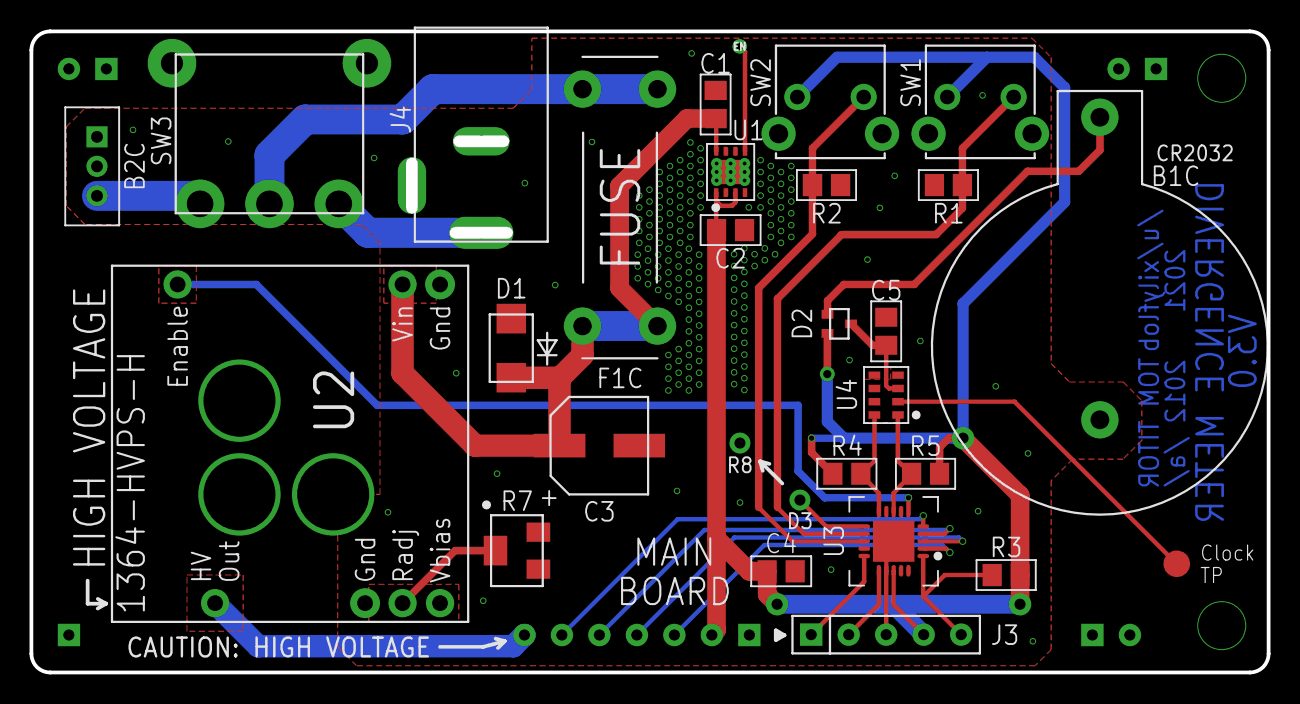
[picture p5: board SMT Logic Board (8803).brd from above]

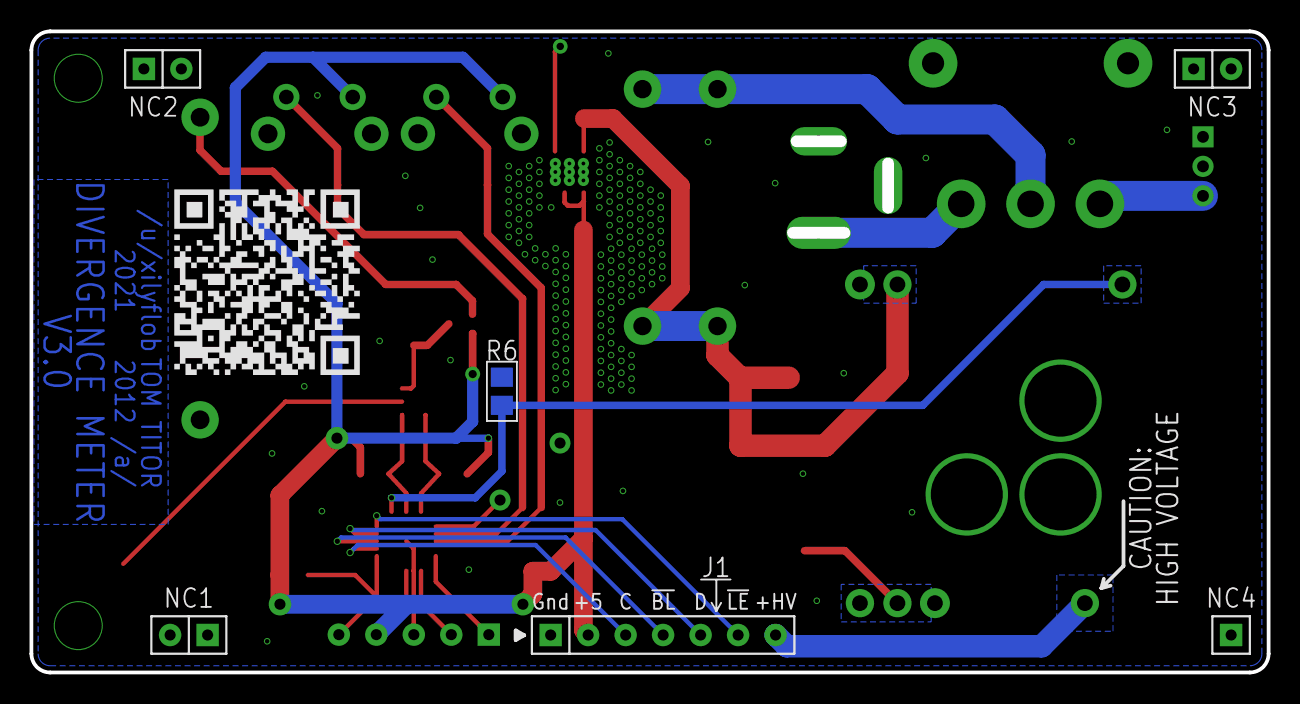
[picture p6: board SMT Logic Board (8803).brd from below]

Board: 2 copper layers, 83.8 x 43.4 mm, 32 parts (6 on the bottom side), 23 nets.

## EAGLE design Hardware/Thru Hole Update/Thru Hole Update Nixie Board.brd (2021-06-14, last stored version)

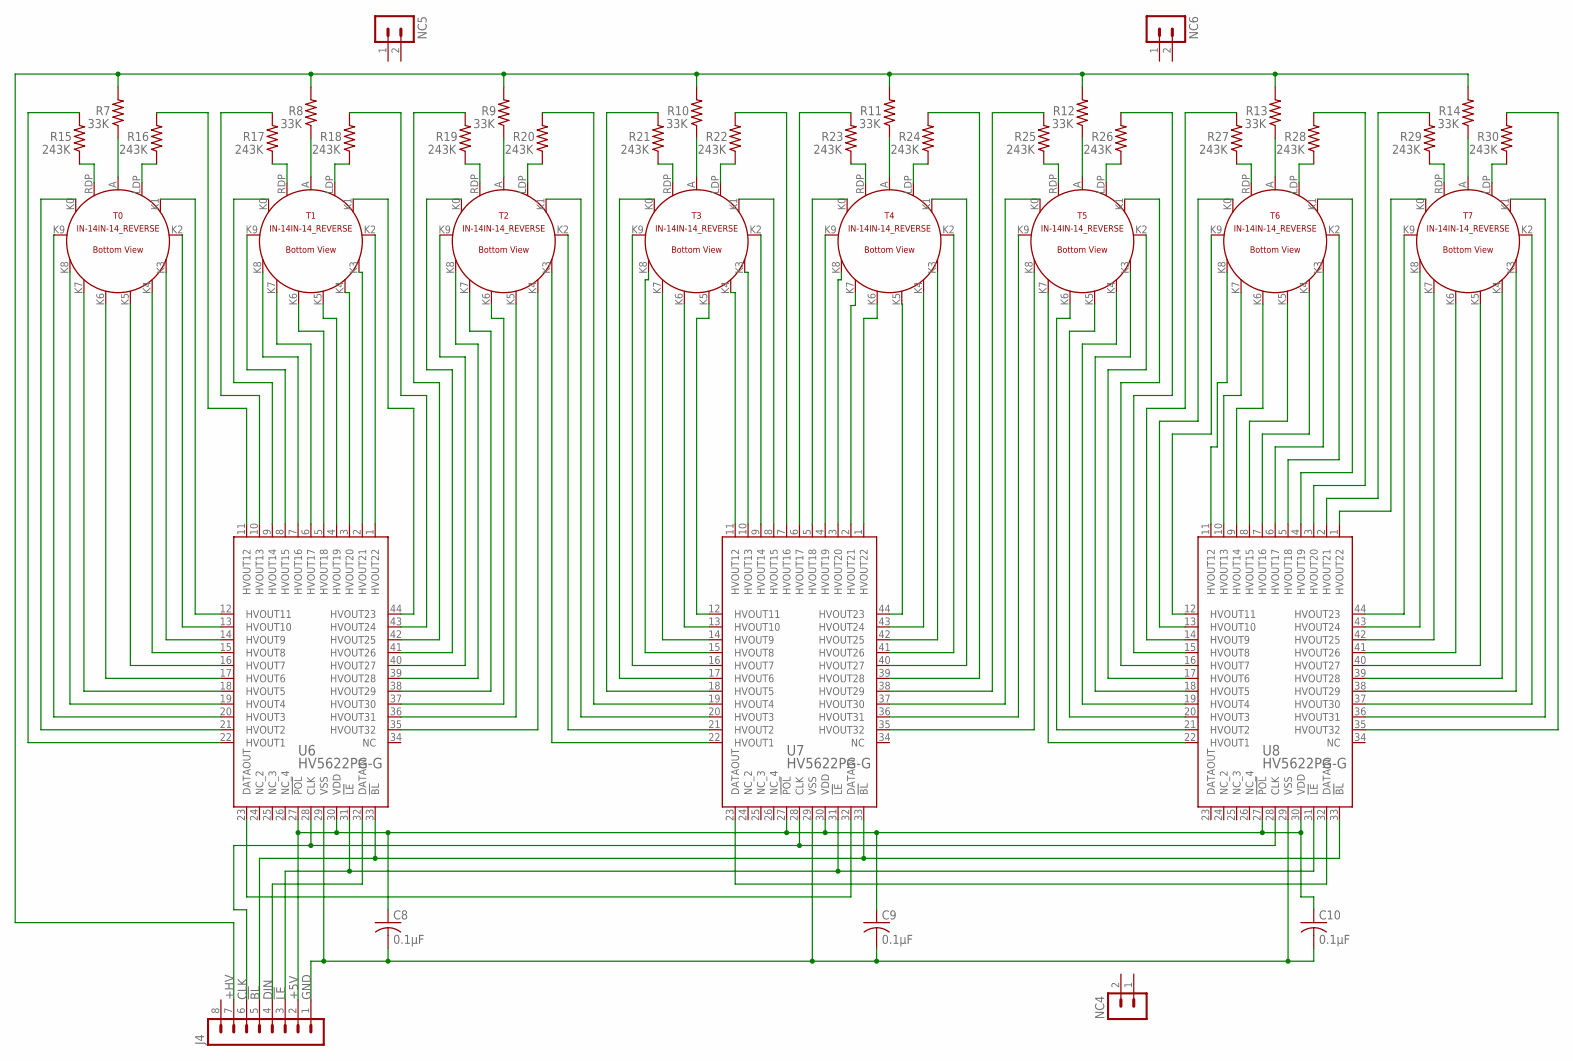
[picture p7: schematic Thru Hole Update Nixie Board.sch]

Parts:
C8, C9, C10: 0.1µF; C025-040X050
J4: 1; MA08
NC4, NC5, NC6: MA02
R7, R8, R9, R10, R11, R12, R13, R14: 33K; 0207/10
R15, R16, R17, R18, R19, R20, R21, R22, R23, R24, R25, R26, R27, R28, R29, R30: 243K; 0207/10
T0, T1, T2, T3, T4, T5, T6, T7: IN-14IN-14_REVERSE; IN-14_REVERSE
U6, U7, U8: HV5622PG-G; QFP-44

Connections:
!BL!: J4.5, U6.33 (!BL), U7.33 (!BL), U8.33 (!BL)
!LE!: J4.3, U6.31 (!LE), U7.31 (!LE), U8.31 (!LE)
+5V: C8.1, C9.1, C10.1, J4.2, U6.27 (!POL), U6.30 (VDD), U7.27 (!POL), U7.30 (VDD), U8.27 (!POL), U8.30 (VDD)
+HV: J4.7, R7.2, R8.2, R9.2, R10.2, R11.2, R12.2, R13.2, R14.2
CLK: J4.6, U6.28 (CLK), U7.28 (CLK), U8.28 (CLK)
DIN: J4.4, U6.32 (DATAIN)
GND: C8.2, C9.2, C10.2, J4.1, U6.29 (VSS), U7.29 (VSS), U8.29 (VSS)
T0A: R7.1, T0.A
T1A: R8.1, T1.A
T2A: R9.1, T2.A
T3A: R10.1, T3.A
T4A: R11.1, T4.A
T5A: R12.1, T5.A
T6A: R13.1, T6.A
T7A: R14.1, T7.A
U5-T0K0: T0.K0, U6.21 (HVOUT2)
U5-T0K1: T0.K1, U6.12 (HVOUT11)
U5-T0K2: T0.K2, U6.13 (HVOUT10)
U5-T0K3: T0.K3, U6.14 (HVOUT9)
U5-T0K4: T0.K4, U6.15 (HVOUT8)
U5-T0K5: T0.K5, U6.16 (HVOUT7)
U5-T0K6: T0.K6, U6.17 (HVOUT6)
U5-T0K7: T0.K7, U6.18 (HVOUT5)
U5-T0K8: T0.K8, U6.19 (HVOUT4)
U5-T0K9: T0.K9, U6.20 (HVOUT3)
U5-T0LDP: R16.2, U6.11 (HVOUT12)
U5-T0LDP1: R16.1, T0.LDP
U5-T0RDP: R15.2, U6.22 (HVOUT1)
U5-T0RDP1: R15.1, T0.RDP
U5-T1K0: T1.K0, U6.9 (HVOUT14)
U5-T1K1: T1.K1, U6.44 (HVOUT23)
U5-T1K2: T1.K2, U6.1 (HVOUT22)
U5-T1K3: T1.K3, U6.2 (HVOUT21)
U5-T1K4: T1.K4, U6.3 (HVOUT20)
U5-T1K5: T1.K5, U6.4 (HVOUT19)
U5-T1K6: T1.K6, U6.5 (HVOUT18)
U5-T1K7: T1.K7, U6.6 (HVOUT17)
U5-T1K8: T1.K8, U6.7 (HVOUT16)
U5-T1K9: T1.K9, U6.8 (HVOUT15)
U5-T1LDP: R18.2, U6.43 (HVOUT24)
U5-T1LDP1: R18.1, T1.LDP
U5-T1RDP: R17.2, U6.10 (HVOUT13)
U5-T1RDP1: R17.1, T1.RDP
U5-T2K0: T2.K0, U6.41 (HVOUT26)
U5-T2K4: T2.K4, U6.35 (HVOUT32)
U5-T2K5: T2.K5, U6.36 (HVOUT31)
U5-T2K6: T2.K6, U6.37 (HVOUT30)
U5-T2K7: T2.K7, U6.38 (HVOUT29)
U5-T2K8: T2.K8, U6.39 (HVOUT28)
U5-T2K9: T2.K9, U6.40 (HVOUT27)
U5-T2RDP: R19.2, U6.42 (HVOUT25)
U5-T2RDP1: R19.1, T2.RDP
U5-U6: U6.23 (DATAOUT), U7.32 (DATAIN)
U6-T2K1: T2.K1, U7.20 (HVOUT3)
U6-T2K2: T2.K2, U7.21 (HVOUT2)
U6-T2K3: T2.K3, U7.22 (HVOUT1)
U6-T2LDP: R20.2, U7.19 (HVOUT4)
U6-T2LDP1: R20.1, T2.LDP
U6-T3K0: T3.K0, U7.17 (HVOUT6)
U6-T3K1: T3.K1, U7.8 (HVOUT15)
U6-T3K2: T3.K2, U7.9 (HVOUT14)
U6-T3K3: T3.K3, U7.10 (HVOUT13)
U6-T3K4: T3.K4, U7.11 (HVOUT12)
U6-T3K5: T3.K5, U7.12 (HVOUT11)
U6-T3K6: T3.K6, U7.13 (HVOUT10)
U6-T3K7: T3.K7, U7.14 (HVOUT9)
U6-T3K8: T3.K8, U7.15 (HVOUT8)
U6-T3K9: T3.K9, U7.16 (HVOUT7)
U6-T3LDP: R22.2, U7.7 (HVOUT16)
U6-T3LDP1: R22.1, T3.LDP
U6-T3RDP: R21.2, U7.18 (HVOUT5)
U6-T3RDP1: R21.1, T3.RDP
U6-T4K0: T4.K0, U7.5 (HVOUT18)
U6-T4K1: T4.K1, U7.40 (HVOUT27)
U6-T4K2: T4.K2, U7.41 (HVOUT26)
U6-T4K3: T4.K3, U7.42 (HVOUT25)
U6-T4K4: T4.K4, U7.43 (HVOUT24)
U6-T4K5: T4.K5, U7.44 (HVOUT23)
U6-T4K6: T4.K6, U7.1 (HVOUT22)
U6-T4K7: T4.K7, U7.2 (HVOUT21)
U6-T4K8: T4.K8, U7.3 (HVOUT20)
U6-T4K9: T4.K9, U7.4 (HVOUT19)
U6-T4LDP: R24.2, U7.39 (HVOUT28)
U6-T4LDP1: R24.1, T4.LDP
U6-T4RDP: R23.2, U7.6 (HVOUT17)
U6-T4RDP1: R23.1, T4.RDP
U6-T5K0: T5.K0, U7.37 (HVOUT30)
U6-T5K8: T5.K8, U7.35 (HVOUT32)
U6-T5K9: T5.K9, U7.36 (HVOUT31)
U6-T5RDP: R25.2, U7.38 (HVOUT29)
U6-T5RDP1: R25.1, T5.RDP
U6-U7: U7.23 (DATAOUT), U8.32 (DATAIN)
U7-T5K1: T5.K1, U8.16 (HVOUT7)
U7-T5K2: T5.K2, U8.17 (HVOUT6)
U7-T5K3: T5.K3, U8.18 (HVOUT5)
U7-T5K4: T5.K4, U8.19 (HVOUT4)
U7-T5K5: T5.K5, U8.20 (HVOUT3)
U7-T5K6: T5.K6, U8.21 (HVOUT2)
U7-T5K7: T5.K7, U8.22 (HVOUT1)
U7-T5LDP: R26.2, U8.15 (HVOUT8)
U7-T5LDP1: R26.1, T5.LDP
U7-T6K0: T6.K0, U8.13 (HVOUT10)
U7-T6K1: T6.K1, U8.4 (HVOUT19)
U7-T6K2: T6.K2, U8.5 (HVOUT18)
U7-T6K3: T6.K3, U8.6 (HVOUT17)
U7-T6K4: T6.K4, U8.7 (HVOUT16)
U7-T6K5: T6.K5, U8.8 (HVOUT15)
U7-T6K6: T6.K6, U8.9 (HVOUT14)
U7-T6K7: T6.K7, U8.10 (HVOUT13)
U7-T6K8: T6.K8, U8.11 (HVOUT12)
U7-T6K9: T6.K9, U8.12 (HVOUT11)
U7-T6LDP: R28.2, U8.3 (HVOUT20)
U7-T6LDP1: R28.1, T6.LDP
U7-T6RDP: R27.2, U8.14 (HVOUT9)
U7-T6RDP1: R27.1, T6.RDP
U7-T7K0: T7.K0, U8.1 (HVOUT22)
U7-T7K1: T7.K1, U8.36 (HVOUT31)
U7-T7K2: T7.K2, U8.37 (HVOUT30)
U7-T7K3: T7.K3, U8.38 (HVOUT29)
U7-T7K4: T7.K4, U8.39 (HVOUT28)
U7-T7K5: T7.K5, U8.40 (HVOUT27)
U7-T7K6: T7.K6, U8.41 (HVOUT26)
U7-T7K7: T7.K7, U8.42 (HVOUT25)
U7-T7K8: T7.K8, U8.43 (HVOUT24)
U7-T7K9: T7.K9, U8.44 (HVOUT23)
U7-T7LDP: R30.2, U8.35 (HVOUT32)
U7-T7LDP1: R30.1, T7.LDP
U7-T7RDP: R29.2, U8.2 (HVOUT21)
U7-T7RDP1: R29.1, T7.RDP

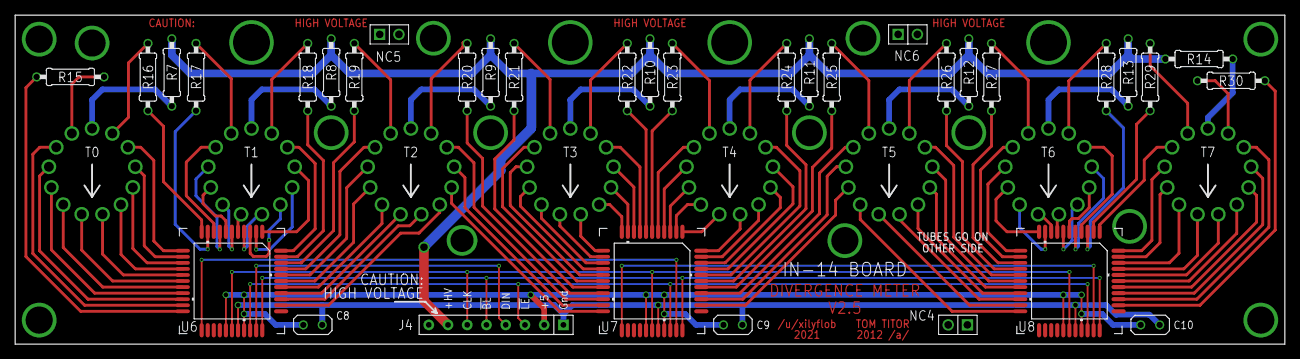
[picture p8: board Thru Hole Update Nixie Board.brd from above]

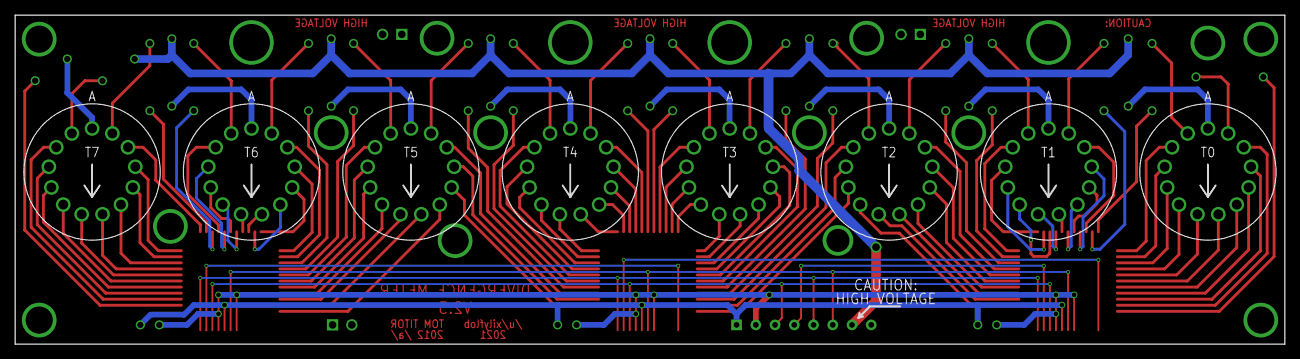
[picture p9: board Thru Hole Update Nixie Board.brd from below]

Board: 2 copper layers, 167.6 x 43.4 mm, 42 parts (8 on the bottom side), 129 nets.

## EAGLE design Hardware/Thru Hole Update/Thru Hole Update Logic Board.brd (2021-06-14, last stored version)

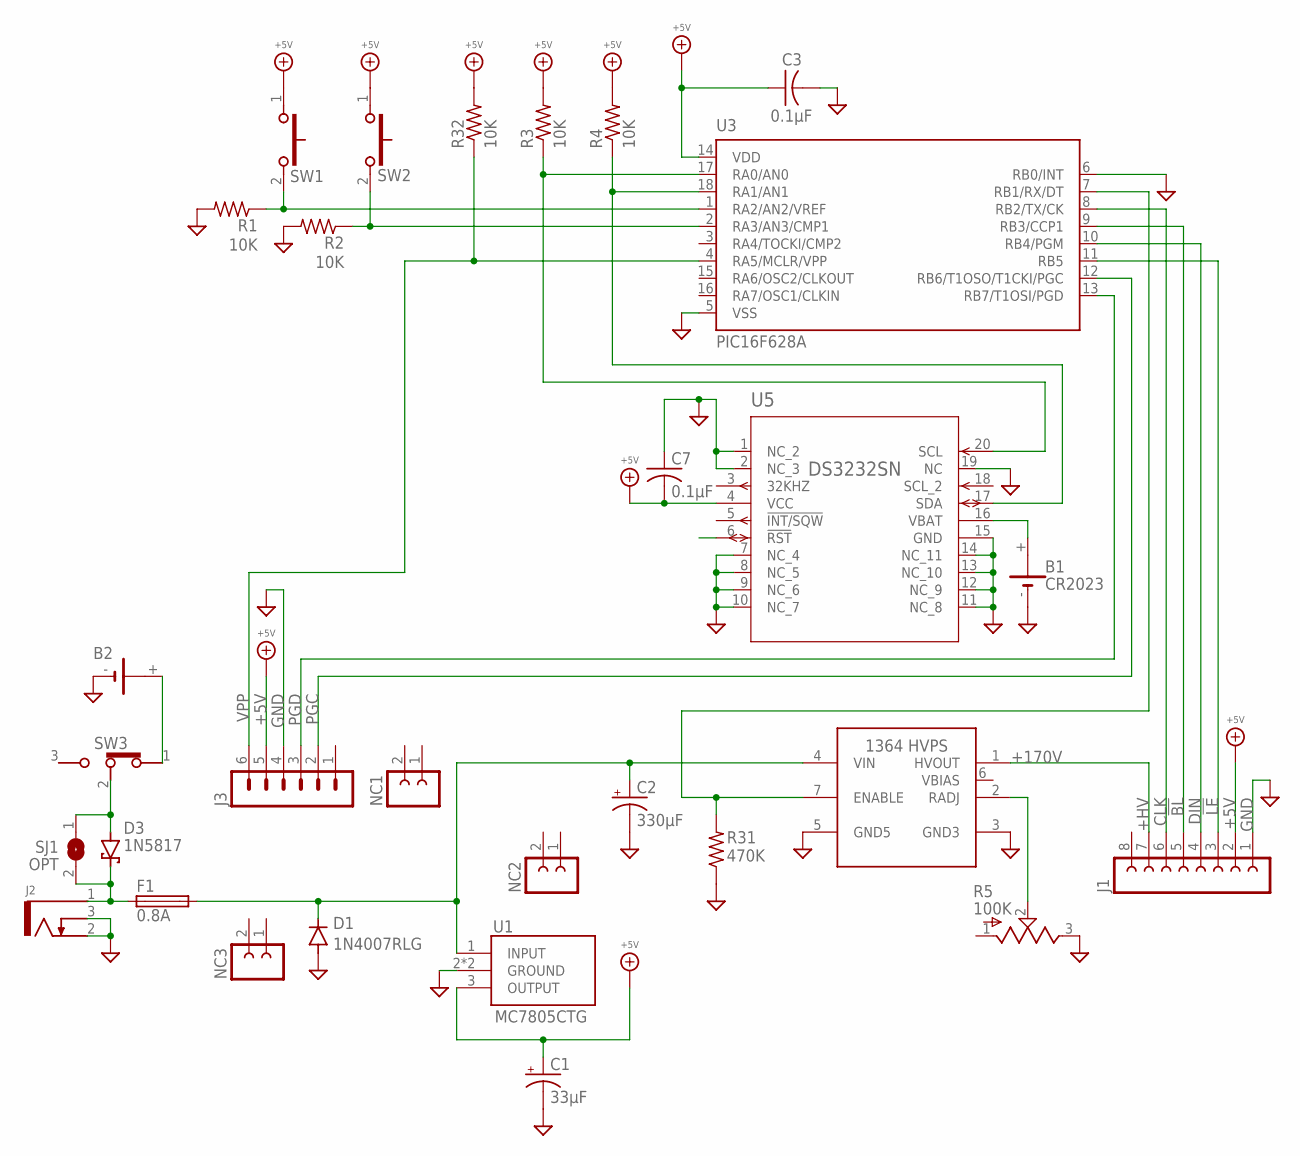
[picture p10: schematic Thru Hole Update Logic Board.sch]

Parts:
B1: CR2023; 103
B2: BATTERYWIRE_ATTACH; 1291
C1: 33μF; E2-5
C2: 330µF; E3,5-8
C3: 0.1µF; C025-040X050
C7: 0.1µF; C0805
D1: 1N4007RLG; DO41-7
D3: 1N5817; DO41-7
F1: 0.8A; 5X20MM
J1: FE08
J2: KLDX-0202-B; KDLX-0202-X
J3: MA06
NC1, NC2, NC3: FE02
R1, R2, R3, R4, R32: 10K; 0207/10
R5: 100K; PV37W
R31: 470K; 0207/10
SJ1: OPT; SJ
SW1, SW2: FSMRA4JH04; FSMRA4JH
SW3: 5MS1S102AM6QES; SLIDE_SPDT_MINI
U1: MC7805CTG; TO-220-3_RA
U2: 1364-HVPS-H
U3: PIC16F628A; DIP-18
U5: DS3232SN; SOIC-20

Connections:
!BL!: J1.5, U3.9 (RB3/CCP1)
!LE!: J1.3, U3.11 (RB5)
+5V: C1.+, C3.1, C7.2, J1.2, J3.5, R3.2, R4.2, R32.2, SW1.1, SW2.1, U1.3 (OUTPUT), U3.14 (VDD), U5.4 (VCC)
+9V: D3.C, F1.1A (1), F1.1B (1), J2.1, SJ1.2
+9V_1: C2.+, D1.C, F1.2A (2), F1.2B (2), U1.1 (INPUT), U2.4 (VIN)
+9V_2: D3.A, SJ1.1, SW3.2 (COM)
+9V_4: B2.+, SW3.1 (POS_1)
+HV: J1.7, U2.1 (HVOUT)
BAT: B1.+, U5.16 (VBAT)
CLK: J1.6, U3.8 (RB2/TX/CK)
DIN: J1.4, U3.10 (RB4/PGM)
ENABLE: R31.2, U2.7 (ENABLE), U3.7 (RB1/RX/DT)
GND: B1.-, B2.-, C1.-, C2.-, C3.2, C7.1, D1.A, J1.1, J2.2, J2.3, J3.4, R1.2, R2.2, R5.3, R31.1, U1.2 (GROUND), U1.2_1 (GROUND), U2.3 (GND3), U2.5 (GND5), U3.5 (VSS), U3.6 (RB0/INT), U5.1 (NC_2), U5.2 (NC_3), U5.7 (NC_4), U5.8 (NC_5), U5.9 (NC_6), U5.10 (NC_7), U5.11 (NC_8), U5.12 (NC_9), U5.13 (NC_10), U5.14 (NC_11), U5.15 (GND), U5.19 (NC)
MYSTERY_3: U5.6 (!RST)
PGC: J3.2, U3.12 (RB6/T1OSO/T1CKI/PGC)
PGD: J3.3, U3.13 (RB7/T1OSI/PGD)
RADJ: R5.2, U2.2 (RADJ)
SCL: R3.1, U3.17 (RA0/AN0), U5.20 (SCL)
SDA: R4.1, U3.18 (RA1/AN1), U5.17 (SDA)
SW1: R1.1, SW1.2, U3.1 (RA2/AN2/VREF)
SW2: R2.1, SW2.2, U3.2 (RA3/AN3/CMP1)
VPP: J3.6, R32.1, U3.4 (RA5/MCLR/VPP)

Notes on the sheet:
+170V

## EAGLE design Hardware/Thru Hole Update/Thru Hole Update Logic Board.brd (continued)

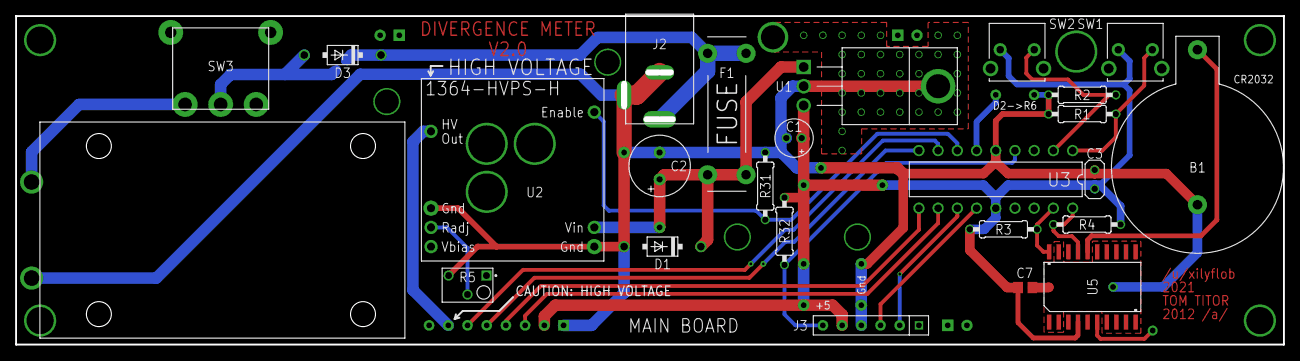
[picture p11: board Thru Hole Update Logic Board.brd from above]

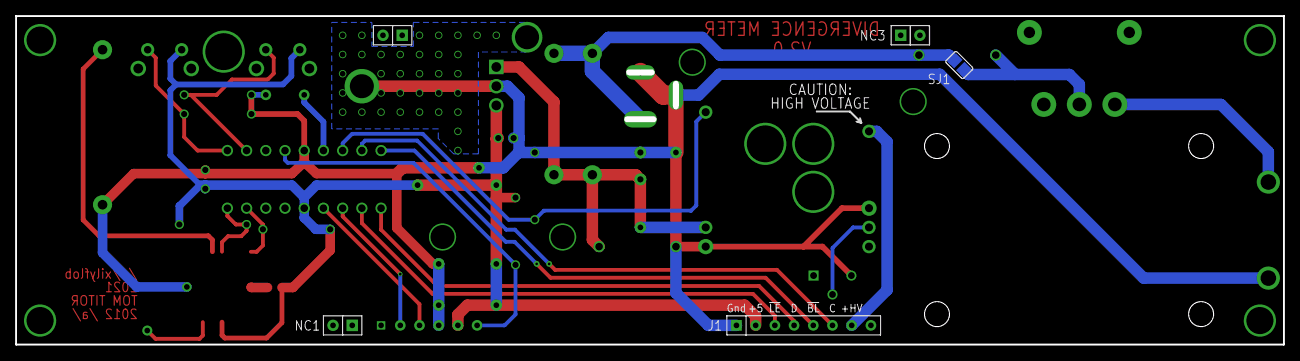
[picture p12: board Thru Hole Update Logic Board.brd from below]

Board: 2 copper layers, 167.6 x 43.4 mm, 30 parts (5 on the bottom side), 21 nets.

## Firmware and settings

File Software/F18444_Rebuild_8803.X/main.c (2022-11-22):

/*
  Main Source File

  File Name:
    main.c

  Summary:
    This is the main file generated using PIC10 / PIC12 / PIC16 / PIC18 MCUs
    Based on the original assembly source code created by Tom Titor of /a/ in 2012
    for the Divergence Meter project.

  Original author:
   Tom Titor of /a/
  
  Rewrite author: 
    /u/xilyflob

  Version:
    1.10

  License:
    GNU GPL V3.0
  
  Generation Information :
      Product Revision  :  PIC10 / PIC12 / PIC16 / PIC18 MCUs - 1.81.7
      Device            :  PIC16F18444
      Driver Version    :  2.00
*/

/* Version History
 * 0.00 - Initial code rewrite, Initial MCC config
 * 0.05 - Initial code rewrite exceeded the program memory of the new device before
 *        even getting close to the end of the original program. Large areas
 *        completely rewritten, again, to produce better assembly code. MCC config
 *        had also been tweaked several times at this point.
 * 0.50 - Reached max program memory AGAIN. This time I gave in and now you should
 *        always compile the code at optimization level 2 or better.
 * 0.75 - Took a close look at the pre generated code that the program is using.
 *        Found several places where the code could be simplified/improved/removed.
 * 1.00 - Feature complete. I2C routines now totally custom, saving like 20% program
 *        space. Current program size is 3112/4096 words and 200/512 bytes of data.
 *        Hardware testing has not occurred yet.
 * 1.05 - There is now two versions of the software, as there is two RTC chips
 *        available. If you are viewing the 8803 version of this file there will
 *        be noted additions or changes to the code, search for 8803 to find relevant
 *        lines.
 * 1.10 - Fixed an issue in the I2CRead function that was causing it to get stuck
 *        after the finishing the write portion and starting the actual read. The
 *        fix was not using the SSP1CON2bits.RSEN function to do the repeated start
 *        instead using SSP1CON2bits.PEN and SSP1CON2bits.SEN to do it. This is
 *        out as ok to do in the 8803 app manual. Also touched up the bad shutdown
 *        recovery in the I2C startup sequence, as it was it wasn't exactly what
 *        the manual called for.
 */

/* Notes by the rewriter
 * 
 * As a general note, you can get the original .asm file to load into the modern
 * MPLABX. However the version of assembly code that is now used is "very" different
 * than what it was written in. Commands are juuuuust different enough to trip up
 * almost every line. For example andwf does not use w or f for the second operator
 * it uses 0 or 1 now and hex and binary numbers are called out differently. I am 
 * unsure if you can force the software to cram the .asm file into the chip as it
 * is, maybe the .hex file. I did not pursue this to any extent at all.
 * 
 * Several of the original subroutines are either not recreated or are radically
 * different compared to their assembly versions. Any delay is a good example.
 * 
 * The EEPROM is slightly altered from its original form since I handled storage
 * and syntax of the display buffer differently. I also could not figure out how
 * to decode the original hex.
 * 
 * The blanking hours are now stored in EEPROM, even with the old processor there
 * was space in the EEPROM for these numbers. I believe they were stored in the 
 * clock  for simplicity in altering the settings but I feel it opens it to data
 * data loss when the backup battery dies.
 * 
 * Brightness control is now run by an honest to god hardware PWM generator, not
 * the admittedly effective, but messy and hard to understand software version that
 * was present in the original program.
 * 
 * I could not understand how the slide flag affected the loader sub well enough
 * to be able to replicate it, thus I have come up with a different way to do the
 * same thing. Unfortunately due to this it means that it is likely much less 
 * efficient.
 * 
 * I had wanted to not work in BCD for readability, but in an effort to reduce 
 * program size I had to do it in the end.
 * 
 * To determine how long a delay is, take the value and put a decimal point after
 * the second digit for milliseconds. (16000 -> 16ms)
 */

/*
    (c) 2018 Microchip Technology Inc. and its subsidiaries. 
    
    Subject to your compliance with these terms, you may use Microchip software and any 
    derivatives exclusively with Microchip products. It is your responsibility to comply with third party 
    license terms applicable to your use of third party software (including open source software) that 
    may accompany Microchip software.
    
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
    IN NO EVENT WILL MICROCHIP BE LIABLE FOR ANY INDIRECT, SPECIAL, PUNITIVE, 
    INCIDENTAL OR CONSEQUENTIAL LOSS, DAMAGE, COST OR EXPENSE OF ANY KIND 
    WHATSOEVER RELATED TO THE SOFTWARE, HOWEVER CAUSED, EVEN IF MICROCHIP 
    HAS BEEN ADVISED OF THE POSSIBILITY OR THE DAMAGES ARE FORESEEABLE. TO 
    THE FULLEST EXTENT ALLOWED BY LAW, MICROCHIP'S TOTAL LIABILITY ON ALL 
    CLAIMS IN ANY WAY RELATED TO THIS SOFTWARE WILL NOT EXCEED THE AMOUNT 
    OF FEES, IF ANY, THAT YOU HAVE PAID DIRECTLY TO MICROCHIP FOR THIS 
    SOFTWARE.
*/

#include "Variables.h"
#include "mcc_generated_files/mcc.h"
#include "limits.h"
#include "Subroutines.h"

//EEPROM Initialization
__EEPROM_DATA(1,R,1,3,0,4,2,6); //these are world lines that appear in the anime/VN, they are in order of appearance
__EEPROM_DATA(0,R,5,7,1,0,2,4); //this is not present in Variables.h since it was duplicating it while in there
__EEPROM_DATA(0,R,5,7,1,0,1,5);
__EEPROM_DATA(0,R,5,2,3,2,9,9);
__EEPROM_DATA(0,R,4,5,6,9,0,3);
__EEPROM_DATA(0,R,4,0,9,4,2,0);
__EEPROM_DATA(0,R,3,3,7,1,8,7);
__EEPROM_DATA(0,R,4,0,9,4,3,1);
__EEPROM_DATA(1,R,0,4,8,5,9,6);
__EEPROM_DATA(10,R,2,7,5,3,4,9);
__EEPROM_DATA(0,R,4,5,6,9,1,4);
__EEPROM_DATA(0,R,5,2,3,3,0,7);
__EEPROM_DATA(0,R,5,7,1,0,4,6);
__EEPROM_DATA(1,R,1,3,0,2,3,8);
__EEPROM_DATA(1,R,0,4,8,5,9,6);

void Startup(void) //one time startup function
{
    // DEVICE INITIALIZATION
    SYSTEM_Initialize(); //MCC generated startup
    TMR0_StartTimer(); //start TMR0, it is used for the random number generator
    //END DEVICE INITIALIZATION

    //PROGRAM INITIALIZATION
    //Interrupt Initialize (global is done later)
    INTERRUPT_PeripheralInterruptEnable();
    
    //Load EEPROM settings into RAM for fast access
    TimeFast = TimeFastStore; //time animation speed 
    TimeAdj = TimeAdjStore; //time adjustment setting initialize
    DateFormat = DateFormatStore; //date format setting initialize
    Brightness = BrightnessStore; //brightness setting initialize
    HourType = HourTypeStore; //12/24 hour setting initialize
    BlankStart = BlankStartStore; //blanking setting initialize
    BlankEnd = BlankEndStore; //blanking setting initialize

    //8803 startup check and initialization
    if ((I2CRead(FlagReg) & 0b00000011) == 0b00000011) //checks the flag register for bits that are set when low voltage limits are reached, 8803
    {
        I2CWrite(FlagReg, 0); //clears the low voltage limit flags, 8803
        I2CWrite(CtrlReg, 0b00000001); //set the reset bit, this holds the upper part of the prescaler in reset, effectively stopping the clock, 8803
        I2CWrite(MinutesReg, 0x30); //this and the next 4 lines set up a default date/time, which is the first time a D-mail is sent
        I2CWrite(HoursReg, 0x12);
        I2CWrite(DateReg, 0x28);
        I2CWrite(MonthReg, 0x7);
        I2CWrite(YearReg, 0x10);
        I2CWrite(CtrlReg, 0b00000000); //clear the reset bit, this releases the hold on the clock, 8803
    }
    
    //Display Initialize
    EmptyTubes(); //blank the tubes
    Loader(); //load the blank tubes to the display
    TubesOn(); //turn the tubes on
    //END PROGRAM INITIALIZATION
    StartupDone = 1; //semi-permanent bit to indicate that startup has been done 
}

void main(void) //Time Display
{
    uint8_t newsec; //latest second read from the clock
    uint8_t oldsec; //the previous second read from the clock
    uint8_t spincount; //counter for the animation at 30s
    uint8_t shift; //slide shift counter
    
    if (!StartupDone) //check if we have done startup or not
        Startup(); //run the initialization
    ei(); //start looking for interrupts, often turned off while in other areas of the program
    while(1) //this all happens until an interrupt sends us places via flags
    {
        if (GoDate == 1) //if the GoDate flag has been set
            DateDisplay(); //display the date
        else if (GoDM == 1) //if the GoDM flag has been set
            DMDisplay(); //go to the DM routines
        oldsec = newsec; //save the last read second for comparison
        newsec = I2CRead(SecondsReg); //get the next second, maybe
        if (newsec == 0x59) //if 59 is read from the clock, 8803
            newsec = I2CRead(SecondsReg); //reread the clock to check that we did not catch it at a bad time, 8803, this is recommended in section 4.12 of the application manual
        BCD2Bin(newsec); //convert to binary for display
        if (newsec != oldsec) //is it actually a different second
        {
            SplitLoad(6); //load the seconds into the buffer
            if (newsec == 0x30) //if we are at a 30s
            {
                DisplayBuf[0] = 0; //in case this was blanked in 12 hour mode
                DisplayBuf[2] = 0; //get the decimal point in
                DisplayBuf[5] = 0; //this one as well
                for (spincount=41; spincount--;) //do 40 animation cycles, no need to save the display since it will loop back to the same numbers
                {
                    for (Pos=8; Pos--;) //tube loop
                    {
                        DisplayBuf[Pos]++; //increment the displayed value
                        if (DisplayBuf[Pos] == 10) //if we get to 10
                            DisplayBuf[Pos] = 0; //wrap to 0
                    }
                    Loader(); //once all the tubes are done
                    _delay(debounce); //tube display time
                }
                DateDisplay(); //display the date for a bit once the animation is done
            }
            else if (newsec == 0x59) //if we are near the top of a minute
            {
                DisplayBufSave(); //make a backup of the display
                for (shift=8; shift--;) //shift the display out the left side
                {
                    for (Pos=0; Pos<8; Pos++) //shift through the tubes
                    { //no fancy c compiler tricks for space saving, only works one way around        
                        DisplayBuf[Pos] = DisplayBuf[Pos + 1]; //make the tube = the next one
                    }
                    DisplayBuf[7] = 10; //except for the last one, it back fills the display with blanks
                    Loader(); //display this round
                    _delay(40000); //time for display
                } //ok, the display is now blank
                for (shift=8; shift--;) //now we shift the blank tubes out and shift in the saved values
                {
                    DisplayBuf[7] = DisplaySave[shift]; //get saved value and put it in the right most tube
                    Loader(); //display this
                    _delay(40000); //time for display
                    for (Pos=0; Pos<8; Pos++) //shift though the tubes
                    { //no fancy c compiler tricks for space saving, only works one way around
                        DisplayBuf[Pos] = DisplayBuf[Pos + 1]; //make the tube = the next one, in preparation for the next value to be added
                    }
                }
            }
            BCD2Bin(I2CRead(MinutesReg)); //get the minutes
            SplitLoad(3); //load the minutes into the buffer
            Temp = I2CRead(HoursReg); //get the hour, in a variable for later checks
            BCD2Bin(Temp); //load the hours into the buffer
            if (Temp == BlankStart) //are we at the start of the blank time?
                TubesOff(); //if so, turn off the display
            else if (Temp == BlankEnd) //are we at the end of the blank time?
                TubesOn(); //if so, turn on the display
            SplitLoad(0); //load the hours into the buffer
            if (HourType == 1) //12 hour mode?
            {
                if (Temp > 0x12) //is the current hour 13+?
                {
                    DisplayBuf[0] -= 1; //subtract 12 if so
                    DisplayBuf[1] -= 2;
                }
                if (DisplayBuf[0] == 0) //is the hour below 10?
                {
                    DisplayBuf[0] = 10; //since we are less than 10, the first tube does not need a digit 
                }
            }
            DisplayBuf[2] = R; //right DPs
            DisplayBuf[5] = R;
            if (DisplayBuf[7] & 1) //if seconds are even, swap to left DP
            {
                DisplayBuf[2] = L; //left DPs
                DisplayBuf[5] = L;
            }
            if (TimeAdj != 0) //if there is a time adjust setting
            {
                TimeAdj--; //decrement, this is basically a counter
                if (TimeAdj == 0) //if we are now at 0
                {
                    while(I2CRead(SecondsReg) != 0b00000001){} //wait until we get a 1 in the seconds register
                    if (TimeFast == 1) //if we are set up for moving backward
                        I2CWrite(SecondsReg, 0b00000000); //take that 1 and make it a 0
                    else //if we are setup for moving forward
                        I2CWrite(SecondsReg, 0b00000010); //take that 1 and make it a 2
                    TimeAdj = TimeAdjStore; //reset the counter from the stored setting
                }
            }
            if ((DisplayBuf[3]|DisplayBuf[4]|DisplayBuf[6]|DisplayBuf[7]) == 0) //all these positions must be 0 to be true
            {
                DisplayBufSave(); //save the display
                FixedWL(); //run a fixed animation
            }
            Loader(); //load it all to the tubes
            _delay(debounce); //display time
        }
    }
}

void DateDisplay(void)
{
    GoDate = 0; //clear the flag in case we got here via that
    di(); //turn off interrupts, buttons are used for other things here
    BCD2Bin(I2CRead(DateReg)); //get the date
    SplitLoad(3); //load the date into the buffer
    BCD2Bin(I2CRead(MonthReg)); //get the month
    SplitLoad(0); //load the month into the buffer
    BCD2Bin(I2CRead(YearReg)); //get the year
    SplitLoad(6); //load the year into the buffer
    DisplayBuf[2] = 10; //blank separating tubes
    DisplayBuf[5] = 10;
    if (DateFormat == 1) //if DDMMYY is preferred 
    {
        Temp = DisplayBuf[0]; //quick save of the month
        Pos = DisplayBuf[1]; //borrowing this here to save memory
        DisplayBuf[0] = DisplayBuf[3]; //flip the month 10s over
        DisplayBuf[1] = DisplayBuf[4]; //flip the month 1s over
        DisplayBuf[3] = Temp; //flip the day 10s over
        DisplayBuf[4] = Pos; //flip the day 1s over
    }
    while (SW2_GetValue()){} //wait for SW2 to be released
    Loader(); //display the date
    _delay(debounce); //give the tubes a second to display
    for (Pos=121; Pos--;) //loop here, showing the date, for about 3 seconds 
    {
        if (SW2_GetValue()) //check if SW2 got pressed again
            Settings(); //go to the settings
        _delay(debounce); //small delay
    }
    return; //back to the time
}

void DMDisplay(void)
{
    uint8_t seedadr = 0x77; //starting EEPROM address for loading saved values 
    
    di(); //turn off interrupts, buttons are used for other things here
    GoDM = 0; //clear flag if we got here by interrupt
    EEPROMBufferFill(seedadr);
    Loader(); //show the WL
    seedadr = 0x07; //move the starting point to the "first" number of the next WL
    while (1) //main loop, i am not happy with this double while loop thing, may implement 4th button press type to avoid this
    {
        Temp = Buttons(); //get a button press
        if (Temp == 1) //if short SW1
            RandomWL(); //do a random number
        else if (Temp == 2) //if long SW1
        {
            while (1) //sub loop
            {
                if (seedadr == 0x7F) //this is the address that will be present after the last WL
                    break; //leave sub loop
                EEPROMBufferFill(seedadr);
                DisplayBufSave(); //backup the display buffer
                FixedWL(); //animation returning to original state
                seedadr += 8; //move the starting point to the "first" number of the next WL
                Temp = Buttons(); //get another button press
                if (Temp == 1) //if short SW1
                    continue; //go around again for the next WL
                else if (Temp == 2) //if long SW1
                    return; //go to clock
                else //if SW2, user defined WL
                {
                    EmptyTubes(); //clear tube buffer in preparation for setting the WL
                    DisplayBuf[1] = R; //set the DP
                    TubeValuePicker(0); //cycle for setting the WL
                    for (Pos=9; Pos--;) //this will blink the tubes 4 times (4 on 4 off)
                    {
                        BL_Toggle(); //flip the blanking bit
                        _delay(28000); //delay for a bit
                    }
                    DisplayBufSave(); //save the user set number here
                    while (1) //loop this last part
                    {
                        Temp = Buttons(); //get a button return
                        if (Temp == 1) //if short SW1
                        {
                            if (Toggle == 1) //if we are on an even loop
                                FixedWL(); //do the fixed animation
                            else //if on the odd loop
                                RandomWL(); //random WL and animation
                            Toggle ^= 1; //flip the toggle bit
                        }
                        else //if anything else
                            return; //go back to the time
                    }
                }
            }
        }
        else //we get here if a 3 (SW2) was returned
            return; //back to the time
    }
}

void Settings(void)
{
    di(); //turn off interrupts, buttons are used for other things here
    EmptyTubes(); //clear tubes
    DisplayBuf[4] = 1; //load the version number
    DisplayBuf[5] = L;
    DisplayBuf[6] = 0;
    DisplayBuf[7] = 5;
    Loader(); //display the version number
    while (SW2_GetValue()){} //wait for SW2 release
    _delay(debounce); //debounce the tubes/button
    EmptyTubes(); //empty the tubes
    DisplayBuf[0] = 0; //setting #1
    DisplayBuf[1] = 1;
    BCDSetInc(0x23, 0, HoursReg); //do the hour setting
    DisplayBuf[1]++; //setting #2
    BCDSetInc(0x59, 0, MinutesReg); //do the minute setting
    DisplayBuf[1]++; //setting #3
    OtherSetInc(1, 0, &HourTypeStore, &HourType); //do the hour format setting
    DisplayBuf[1]++; //setting #4
    BCDSetInc(0x31, 0x1, DateReg); //do the date setting
    DisplayBuf[1]++; //setting #5
    BCDSetInc(0x12, 0x1, MonthReg); //do the month setting
    DisplayBuf[1]++; //setting #6
    BCDSetInc(0x99, 0, MonthReg); //do the year setting
    DisplayBuf[1]++; //setting #7
    OtherSetInc(1, 0, &DateFormatStore, &DateFormat); //do the date format setting
    DisplayBuf[1]++; //setting #8
    BCDSetInc(0x23, 0, BlankStarti2c); //do the blank start hour setting
    EEPROM_Write(&BlankStartStore, BlankStart); //save the setting
    DisplayBuf[1]++; //setting #9
    BCDSetInc(0x23, 0, BlankEndi2c); //do the blank ending hour setting
    EEPROM_Write(&BlankEndStore, BlankEnd); //save the setting
    DisplayBuf[0]++; //setting #10
    DisplayBuf[1] = 0;
    DisplayBuf[2] = R; //assuming that TimeFast is default
    if (TimeFast == 0) //but if it is not
        DisplayBuf[2] = 10; //blank the tube
    TimeSet = 1; //set the flag so we know that we are doing the setting version
    DisplayBuf[3] = 0; //set the rest of the tubes to 0
    DisplayBuf[4] = 0;
    DisplayBuf[5] = 0;
    DisplayBuf[6] = 0;
    DisplayBuf[7] = 0;
    TubeValuePicker(3); //set the values for the time delay interval
    TimeSet = 0; //done with the flag
    if (DisplayBuf[2] == R) //check for TimeFast setting
        TimeFast = 1; //time adjustments will now be negative
    else // will get here if the tube is blank
        TimeFast = 0; //time adjustments will now be positive
    TimeAdj = 0; //clear the TimeAdj variable, needs to be empty for what comes next
    for (Pos=3; Pos<8; Pos++) //starting at position  3 since that is where the numbers start from
    { //must go in order for this one, no space saving tricks
        TimeAdj = (TimeAdj * 10) + DisplayBuf[Pos]; //add the current position in
        if (Pos == 6 && TimeAdj > 6554) //if the user put in a value that is too large
        {
            TimeAdj = USHRT_MAX; //set the adjustment to the maximum possible
            break; //get out of here
        }
    }//setting now set
    EEPROM_Write(&TimeFastStore, TimeFast); //save the first part of the setting
    EEPROM_Write(&TimeAdjStore, (TimeAdj & 0x00FF)); //save the second part of the setting
    EEPROM_Write((&TimeAdjStore + 1), ((TimeAdj >> 8) & 0x00FF)); //save the final part of the setting
    DisplayBuf[1]++; //setting #11
    OtherSetInc(10, 1, &BrightnessStore, &Brightness); //do the brightness setting
}
/**
 End of File
*/

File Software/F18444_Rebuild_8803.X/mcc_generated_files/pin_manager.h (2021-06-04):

/**
  @Generated Pin Manager Header File

  @Company:
    Microchip Technology Inc.

  @File Name:
    pin_manager.h

  @Summary:
    This is the Pin Manager file generated using PIC10 / PIC12 / PIC16 / PIC18 MCUs

  @Description
    This header file provides APIs for driver for .
    Generation Information :
        Product Revision  :  PIC10 / PIC12 / PIC16 / PIC18 MCUs - 1.81.7
        Device            :  PIC16F18444
        Driver Version    :  2.11
    The generated drivers are tested against the following:
        Compiler          :  XC8 2.31 and above
        MPLAB 	          :  MPLAB X 5.45	
*/

/*
    (c) 2018 Microchip Technology Inc. and its subsidiaries. 
    
    Subject to your compliance with these terms, you may use Microchip software and any 
    derivatives exclusively with Microchip products. It is your responsibility to comply with third party 
    license terms applicable to your use of third party software (including open source software) that 
    may accompany Microchip software.
    
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
    IN NO EVENT WILL MICROCHIP BE LIABLE FOR ANY INDIRECT, SPECIAL, PUNITIVE, 
    INCIDENTAL OR CONSEQUENTIAL LOSS, DAMAGE, COST OR EXPENSE OF ANY KIND 
    WHATSOEVER RELATED TO THE SOFTWARE, HOWEVER CAUSED, EVEN IF MICROCHIP 
    HAS BEEN ADVISED OF THE POSSIBILITY OR THE DAMAGES ARE FORESEEABLE. TO 
    THE FULLEST EXTENT ALLOWED BY LAW, MICROCHIP'S TOTAL LIABILITY ON ALL 
    CLAIMS IN ANY WAY RELATED TO THIS SOFTWARE WILL NOT EXCEED THE AMOUNT 
    OF FEES, IF ANY, THAT YOU HAVE PAID DIRECTLY TO MICROCHIP FOR THIS 
    SOFTWARE.
*/

#ifndef PIN_MANAGER_H
#define PIN_MANAGER_H

/**
  Section: Included Files
*/

#include <xc.h>

#define INPUT   1
#define OUTPUT  0

#define HIGH    1
#define LOW     0

#define ANALOG      1
#define DIGITAL     0

#define PULL_UP_ENABLED      1
#define PULL_UP_DISABLED     0

// get/set RA2_UNUSED aliases
#define RA2_UNUSED_TRIS                 TRISAbits.TRISA2
#define RA2_UNUSED_LAT                  LATAbits.LATA2
#define RA2_UNUSED_PORT                 PORTAbits.RA2
#define RA2_UNUSED_WPU                  WPUAbits.WPUA2
#define RA2_UNUSED_OD                   ODCONAbits.ODCA2
#define RA2_UNUSED_ANS                  ANSELAbits.ANSA2
#define RA2_UNUSED_SetHigh()            do { LATAbits.LATA2 = 1; } while(0)
#define RA2_UNUSED_SetLow()             do { LATAbits.LATA2 = 0; } while(0)
#define RA2_UNUSED_Toggle()             do { LATAbits.LATA2 = ~LATAbits.LATA2; } while(0)
#define RA2_UNUSED_GetValue()           PORTAbits.RA2
#define RA2_UNUSED_SetDigitalInput()    do { TRISAbits.TRISA2 = 1; } while(0)
#define RA2_UNUSED_SetDigitalOutput()   do { TRISAbits.TRISA2 = 0; } while(0)
#define RA2_UNUSED_SetPullup()          do { WPUAbits.WPUA2 = 1; } while(0)
#define RA2_UNUSED_ResetPullup()        do { WPUAbits.WPUA2 = 0; } while(0)
#define RA2_UNUSED_SetPushPull()        do { ODCONAbits.ODCA2 = 0; } while(0)
#define RA2_UNUSED_SetOpenDrain()       do { ODCONAbits.ODCA2 = 1; } while(0)
#define RA2_UNUSED_SetAnalogMode()      do { ANSELAbits.ANSA2 = 1; } while(0)
#define RA2_UNUSED_SetDigitalMode()     do { ANSELAbits.ANSA2 = 0; } while(0)

// get/set RA4_UNUSED aliases
#define RA4_UNUSED_TRIS                 TRISAbits.TRISA4
#define RA4_UNUSED_LAT                  LATAbits.LATA4
#define RA4_UNUSED_PORT                 PORTAbits.RA4
#define RA4_UNUSED_WPU                  WPUAbits.WPUA4
#define RA4_UNUSED_OD                   ODCONAbits.ODCA4
#define RA4_UNUSED_ANS                  ANSELAbits.ANSA4
#define RA4_UNUSED_SetHigh()            do { LATAbits.LATA4 = 1; } while(0)
#define RA4_UNUSED_SetLow()             do { LATAbits.LATA4 = 0; } while(0)
#define RA4_UNUSED_Toggle()             do { LATAbits.LATA4 = ~LATAbits.LATA4; } while(0)
#define RA4_UNUSED_GetValue()           PORTAbits.RA4
#define RA4_UNUSED_SetDigitalInput()    do { TRISAbits.TRISA4 = 1; } while(0)
#define RA4_UNUSED_SetDigitalOutput()   do { TRISAbits.TRISA4 = 0; } while(0)
#define RA4_UNUSED_SetPullup()          do { WPUAbits.WPUA4 = 1; } while(0)
#define RA4_UNUSED_ResetPullup()        do { WPUAbits.WPUA4 = 0; } while(0)
#define RA4_UNUSED_SetPushPull()        do { ODCONAbits.ODCA4 = 0; } while(0)
#define RA4_UNUSED_SetOpenDrain()       do { ODCONAbits.ODCA4 = 1; } while(0)
#define RA4_UNUSED_SetAnalogMode()      do { ANSELAbits.ANSA4 = 1; } while(0)
#define RA4_UNUSED_SetDigitalMode()     do { ANSELAbits.ANSA4 = 0; } while(0)

// get/set RA5_UNUSED aliases
#define RA5_UNUSED_TRIS                 TRISAbits.TRISA5
#define RA5_UNUSED_LAT                  LATAbits.LATA5
#define RA5_UNUSED_PORT                 PORTAbits.RA5
#define RA5_UNUSED_WPU                  WPUAbits.WPUA5
#define RA5_UNUSED_OD                   ODCONAbits.ODCA5
#define RA5_UNUSED_ANS                  ANSELAbits.ANSA5
#define RA5_UNUSED_SetHigh()            do { LATAbits.LATA5 = 1; } while(0)
#define RA5_UNUSED_SetLow()             do { LATAbits.LATA5 = 0; } while(0)
#define RA5_UNUSED_Toggle()             do { LATAbits.LATA5 = ~LATAbits.LATA5; } while(0)
#define RA5_UNUSED_GetValue()           PORTAbits.RA5
#define RA5_UNUSED_SetDigitalInput()    do { TRISAbits.TRISA5 = 1; } while(0)
#define RA5_UNUSED_SetDigitalOutput()   do { TRISAbits.TRISA5 = 0; } while(0)
#define RA5_UNUSED_SetPullup()          do { WPUAbits.WPUA5 = 1; } while(0)
#define RA5_UNUSED_ResetPullup()        do { WPUAbits.WPUA5 = 0; } while(0)
#define RA5_UNUSED_SetPushPull()        do { ODCONAbits.ODCA5 = 0; } while(0)
#define RA5_UNUSED_SetOpenDrain()       do { ODCONAbits.ODCA5 = 1; } while(0)
#define RA5_UNUSED_SetAnalogMode()      do { ANSELAbits.ANSA5 = 1; } while(0)
#define RA5_UNUSED_SetDigitalMode()     do { ANSELAbits.ANSA5 = 0; } while(0)

// get/set RB4 procedures
#define RB4_SetHigh()            do { LATBbits.LATB4 = 1; } while(0)
#define RB4_SetLow()             do { LATBbits.LATB4 = 0; } while(0)
#define RB4_Toggle()             do { LATBbits.LATB4 = ~LATBbits.LATB4; } while(0)
#define RB4_GetValue()              PORTBbits.RB4
#define RB4_SetDigitalInput()    do { TRISBbits.TRISB4 = 1; } while(0)
#define RB4_SetDigitalOutput()   do { TRISBbits.TRISB4 = 0; } while(0)
#define RB4_SetPullup()             do { WPUBbits.WPUB4 = 1; } while(0)
#define RB4_ResetPullup()           do { WPUBbits.WPUB4 = 0; } while(0)
#define RB4_SetAnalogMode()         do { ANSELBbits.ANSB4 = 1; } while(0)
#define RB4_SetDigitalMode()        do { ANSELBbits.ANSB4 = 0; } while(0)
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

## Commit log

2021-06-13 Original board rebuild added
    Added the Eagle files for the original Tom Titor PCBs that have been remade in the new software.
    [Tom Titor Logic Board Rebuilt.brd, Tom Titor Logic Board Rebuilt.sch, Tom Titor Nixie Board Rebuilt.brd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]
2021-06-13 Library mismatch fix
    Major errors involved with a late change that was made to the component library. Don't let your layout and schematic get out of sync kids.
    [Tom Titor Logic Board Rebuilt.brd, Tom Titor Logic Board Rebuilt.sch, Tom Titor Nixie Board Rebuilt.brd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]
2021-06-14 Thru hole design update version added
    [Thru Hole Update Logic Board.brd, Thru Hole Update Logic Board.sch, Thru Hole Update Nixie Board.brd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]
2021-08-01 SMT designs and data sheets
    Some data sheets and the SMT designs as they stand, because oh god HELP MEH!
    [SMT Logic Board (8803).brd, SMT Logic Board (8803).sch, SMT Logic Board (DS3232).brd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]
2021-08-07 Create Parts Lists.xlsx
    [Parts Lists.xlsx]
2021-08-08 Component numbering fix
    There was a gap from U3 to U5, shifted U5 onwards down one (eg to U4).
    Was also playing the with DR for JLCPCB, some pads etc may be wonky because of this.
    [SMT Logic Board (8803).brd, SMT Logic Board (8803).sch, SMT Nixie Board (HV5623).brd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]
2021-09-04 Conversion of Eagle to KiCad for 8803
    Imported to KiCad and tweaked to fix issues from that.
    [SMT Logic Board (8803).brd, SMT Logic Board (8803).sch]
2022-05-30 Out of date file removal
    I've decided to abandon/delete the eagle versions of the rebuild. They are so hideously out of date that they are of little use at this point. I am also unlikely to ever go back into eagle to fix them.
    [SMT Logic Board (DS3232).brd, SMT Logic Board (DS3232).sch, SMT Nixie Board (HV5622).brd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]
2022-05-30 Update some info files
    [Parts Lists.xlsx]
2022-11-16 Progress update and archive
    [Thru Hole Update Logic Board.brd, Thru Hole Update Logic Board.sch, Thru Hole Update Nixie Board.brd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]

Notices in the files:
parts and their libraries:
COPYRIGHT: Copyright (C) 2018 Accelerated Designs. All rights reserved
